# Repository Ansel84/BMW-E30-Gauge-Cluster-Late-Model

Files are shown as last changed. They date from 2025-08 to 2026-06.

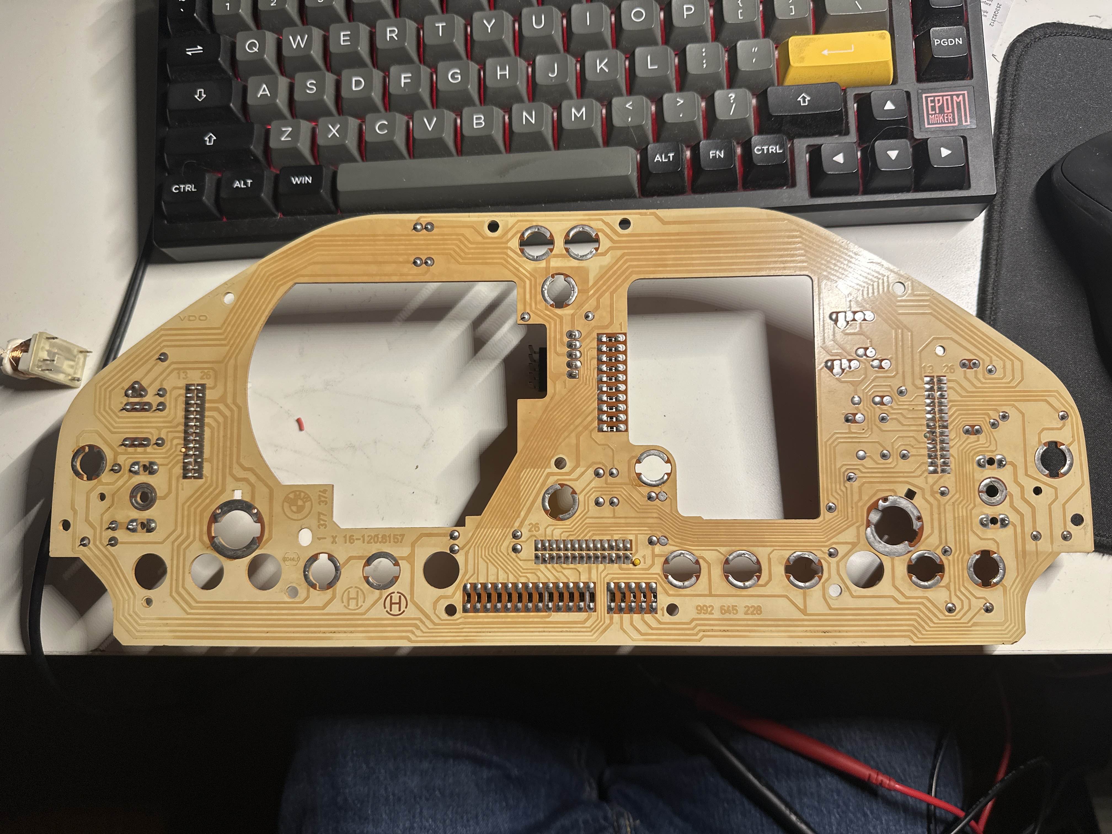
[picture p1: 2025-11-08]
BMW_E30_Late_Cluster_Nexus/Resources/VDO_Nexus_Layout.jpg

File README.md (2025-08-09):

# BMW E30 Gauge Cluster Late Model
The goal for this project is to reverse engineer every PCB in the gauge cluster for Late model year BMW E30's. This includes the main PCB referred to as the "Nexus" board, the SI (Service Interval) board, and the smaller boards that are part of the tachometer and speedometer gauge assemblies.

# Early Model Clusters:
If you have an early model cluster and need parts for that, check out the progress of the early model project here: https://github.com/Ansel84/BMW-E30-Gauge-Cluster-Early-Model

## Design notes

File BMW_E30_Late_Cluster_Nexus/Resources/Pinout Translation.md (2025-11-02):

# Stecker I SL 62 (blau / blue)
Pin	German	English
1	KL 50	Terminal 50 (starter signal)
2	KL 30	Terminal 30 (battery +)
3	Ladekontrolle KL 61	Charge indicator (terminal 61)
4	CHECK	Check control
5	Motronik	Motronic (engine control)
6	(KL 15)	Terminal 15 (ignition on)
7	KL TD	Engine speed signal (TD)
8	Rückwärtsgang	Reverse gear
9	5. Gang	5th gear
10	(KL 15)	Terminal 15 (ignition on)
11	KL 11	Terminal 11
12	KL 56a (Fernlicht)	Terminal 56a (high beam)
13	Blinker rechts	Right turn signal
14	Ladekontr. (KL 15)	Charge indicator (KL 15)
15	frei	Free / unused
16	Ladekontr. (KL 61)	Charge indicator (KL 61)
17	Bremse	Brake
18	Öldruck	Oil pressure
19	(KL 15)	Terminal 15 (ignition on)
20	(KL 31)	Terminal 31 (ground)
21	Bremsbelag 1	Brake pad wear sensor 1
22	Reset	Reset
23	KL 15	Terminal 15 (ignition on)
24	frei	Free / unused
25	Temp. warn	Temperature warning
26	Temp. Geber	Temperature sender
# Stecker II SL 61 (weiß / white)
Pin	German	English
1	Handbremse	Handbrake
2	frei	Free / unused
3	(KL 31)	Terminal 31 (ground)
4	Tank Geber	Fuel level sender
5	Tank warn	Fuel warning
6	KL 15	Terminal 15 (ignition on)
7	Blinker links	Left turn signal
8	(KL 31)	Terminal 31 (ground)
9	frei	Free / unused
10	A	Fuel warning lamp
11	frei	Free / unused
12	KL 31b	Terminal 31b
13	KL R	Terminal R (accessory on)
14	Nebelschlußleuchte	Rear fog lamp
15	frei	Free / unused
16	KL 31	Terminal 31 (ground)
17	frei	Free / unused
18	frei	Free / unused
19	frei	Free / unused
20	frei	Free / unused
21	(KL 31)	Terminal 31 (ground)
22	Nebelbeleucht. vorn	Front fog lamp
23	KL 58k	Terminal 58k (illumination)
24	KL 31g	Terminal 31g (ground group)
25	frei	Free / unused
26	Bremsbelag 2	Brake pad wear sensor 2
# Stecker III SL 60 (gelb / yellow)
Pin	German	English
1	KL 31	Terminal 31 (ground)
2	KL 15	Terminal 15 (ignition on)
3	(KL 31)	Terminal 31 (ground)
4	Tank warn	Fuel warning
5	Tank Geber	Fuel sender
6	(KL 31)	Terminal 31 (ground)
7	KL 58k	Terminal 58k (illumination)
8	KL 31g	Terminal 31g (ground group)
9	KL 50	Terminal 50 (starter signal)
10	KL 30	Terminal 30 (battery +)
11	KL TD	Engine speed signal (TD)
12	(KL 11)	Terminal 11
13	KL R	Terminal R (accessory on)
14	KL 15	Terminal 15 (ignition on)
15	KL 15	Terminal 15 (ignition on)
16	(KL 31)	Terminal 31 (ground)
17	(Tank warn)	Fuel warning
18	(Tank Geber)	Fuel sender
19	(KL 31)	Terminal 31 (ground)
20	KL 58k	Terminal 58k (illumination)
21	KL 31g	Terminal 31g (ground group)
22	KL 50	Terminal 50 (START)
23	KL 30	(Battery+ T30)
24	KL TD	Engine speed signal (TD)
25	KL 11	Fuel Rate Input
26	A	A
# Stecker IV SL 63 (grün / green)
Pin	German	English
1	KL R	Terminal R (accessory on)
2	A	Fuel warning lamp
3	KL 31b	Terminal 31b (ground)
4	KL 31	Terminal 31 (ground)
5	KL 61	Terminal 61 (charging system)
# KF 41–58 (rear connector block)
Pin	German	English
1	Temp. +Ub	Temp. + supply voltage
2	Temp. Masse	Temp. ground
3	Temp. Geber	Temperature sender
4	Reset	Reset
5	KL 15	Terminal 15 (ignition on)
6	NC
7	KL 31	Terminal 31 (ground)
8	KL 30	Terminal 30 (battery +)
9	KL TD	Engine speed signal (TD)
10	KL 11	Terminal 11
11	A	Wheel speed output
12	KVA Sp 2+	Current supply 2+
13	KVA Sp 2–	Current supply 2–
14	KVA Sp 1–	Current supply 1–
15	KVA Sp 1+	Current supply 1+
16	DZM Sp 1–	Tachometer signal 1–
17	DZM Sp 1+	Tachometer signal 1+
18	DZM Sp 2+	Tachometer signal 2+
19	DZM Sp 2–	Tachometer signal 2–
# Lamp Legend (bottom of page)
Letter	German	English
A	Tankwarnleuchte	Fuel warning lamp
B	Instrumentenbeleuchtung	Instrument illumination
C	Blinker links	Left turn indicator
D	Fernlicht	High beam
E	Blinker rechts	Right turn indicator
F	Temperaturwarnleuchte	Temperature warning lamp
G	Öldruck	Oil pressure warning lamp
H	Ladekontrolle	Battery charge indicator
I	Antiblockiersystem	Anti-lock braking system (ABS)
K	Bremskontrolle	Brake warning lamp
L	Bremsbelagverschleißanzeige	Brake pad wear indicator
M	Handbremse	Handbrake indicator
N	Anhängerblinker	Trailer turn indicator
O	Nebelschlußleuchte	Rear fog lamp
P	Nebelscheinwerfer	Front fog lamp
Q	Getriebeausfall	Transmission failure indicator
R	Start frei, Diesel	Diesel start permit
S	Vorglühen, Diesel	Diesel glow plug indicator
T	Check	Check control lamp

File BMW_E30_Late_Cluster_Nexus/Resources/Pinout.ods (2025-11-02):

Stecker 1
Pin | German | English
1 | KL50
2 | KL30
3 | Ladekontrolle KL61
4
5
6
7
8
9
10
11
12
13
14
15
16
17
18
19
20
21
22
23
24
25
26

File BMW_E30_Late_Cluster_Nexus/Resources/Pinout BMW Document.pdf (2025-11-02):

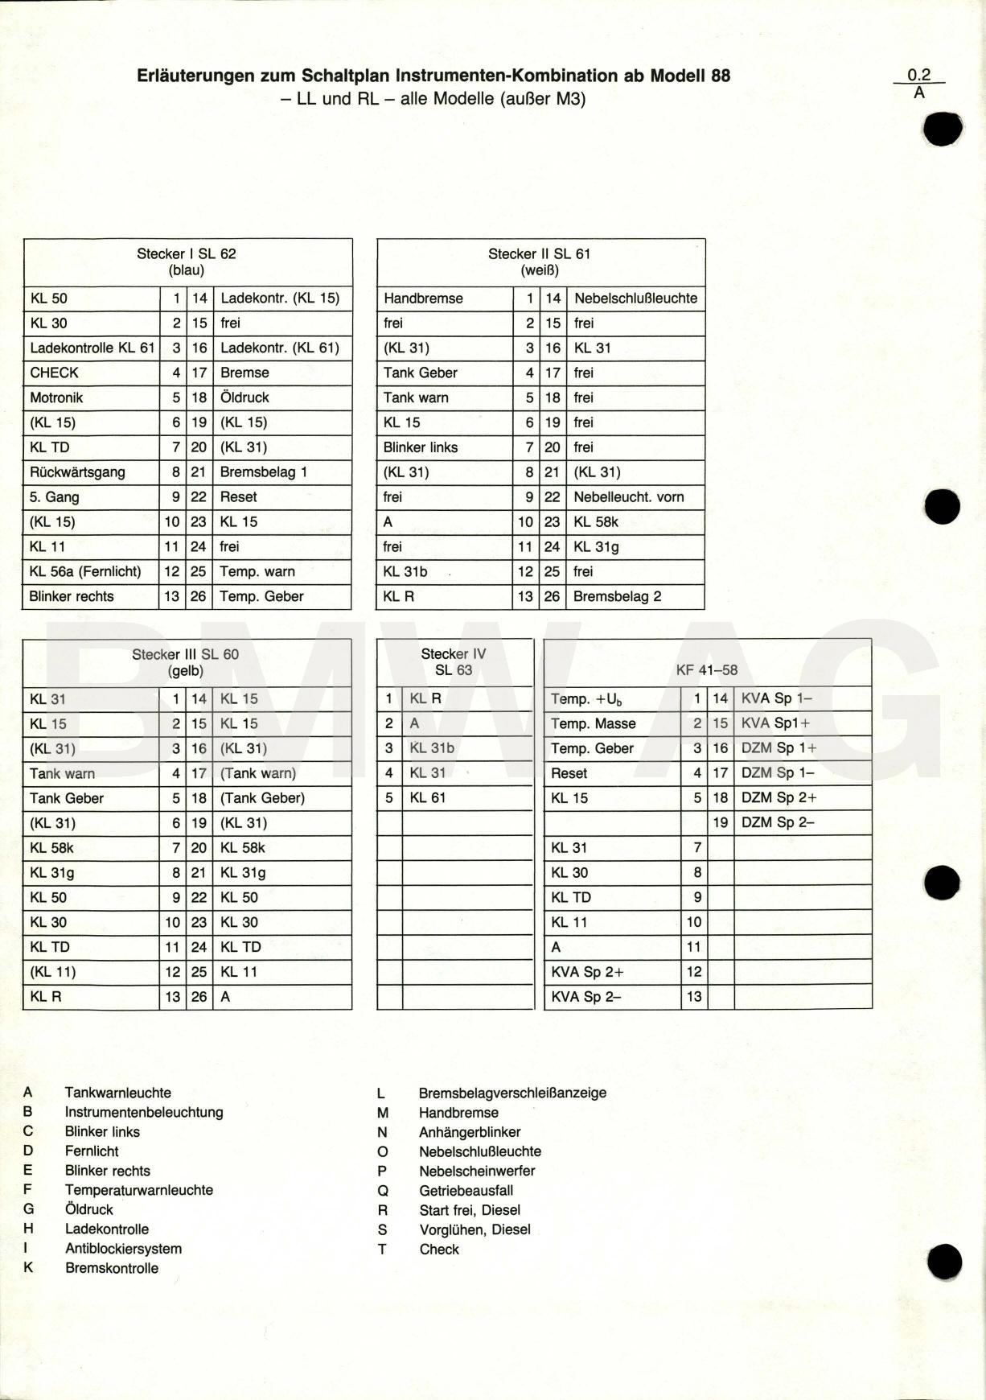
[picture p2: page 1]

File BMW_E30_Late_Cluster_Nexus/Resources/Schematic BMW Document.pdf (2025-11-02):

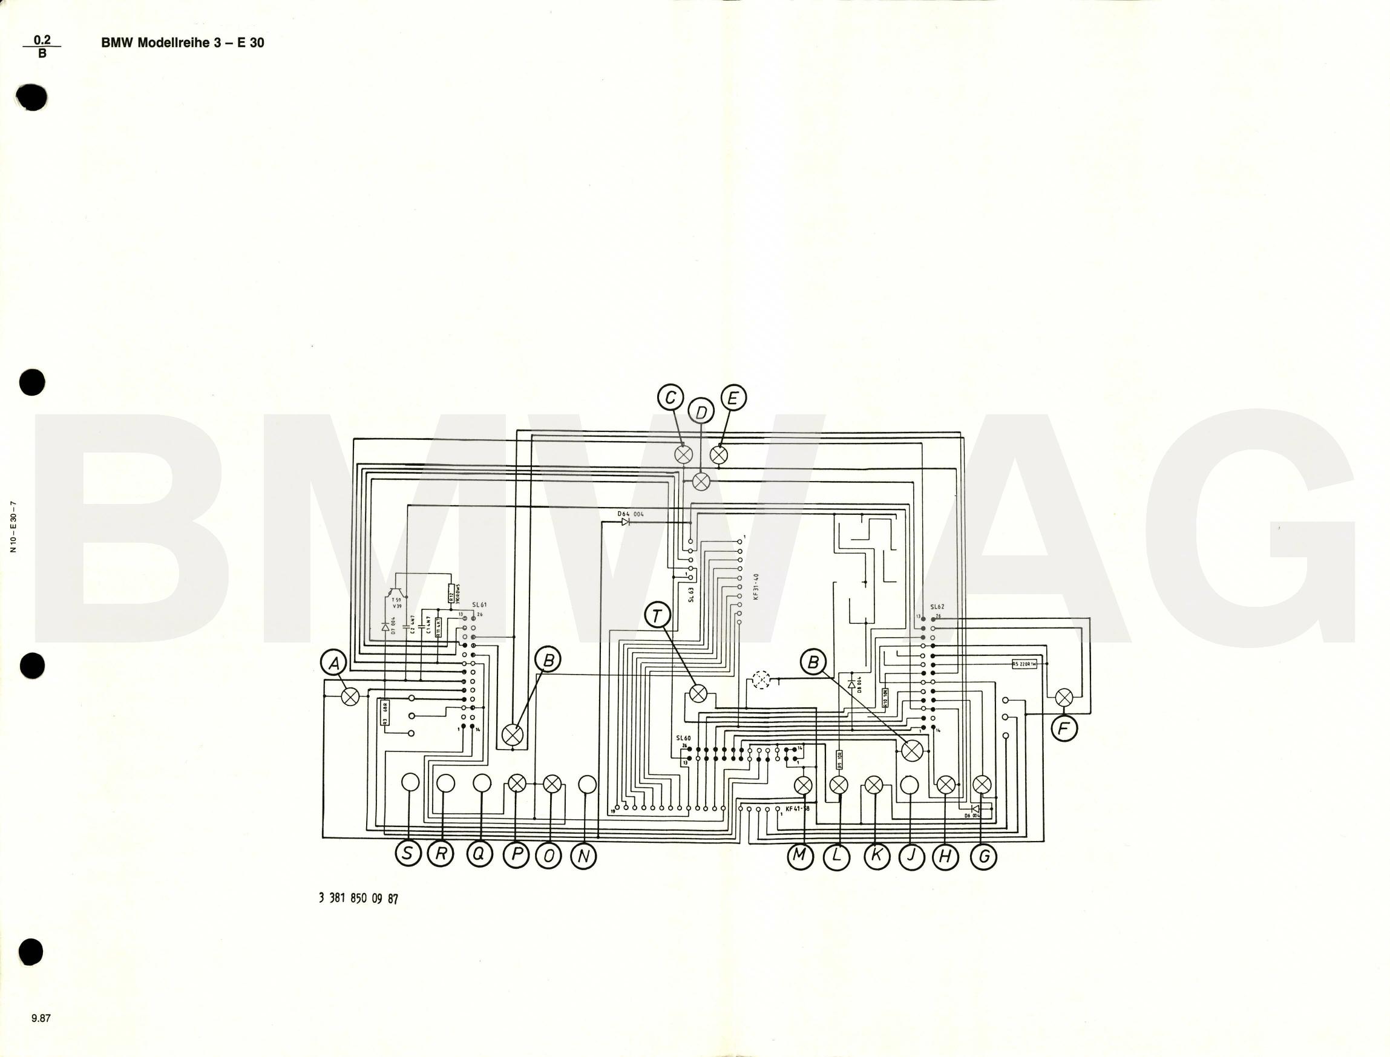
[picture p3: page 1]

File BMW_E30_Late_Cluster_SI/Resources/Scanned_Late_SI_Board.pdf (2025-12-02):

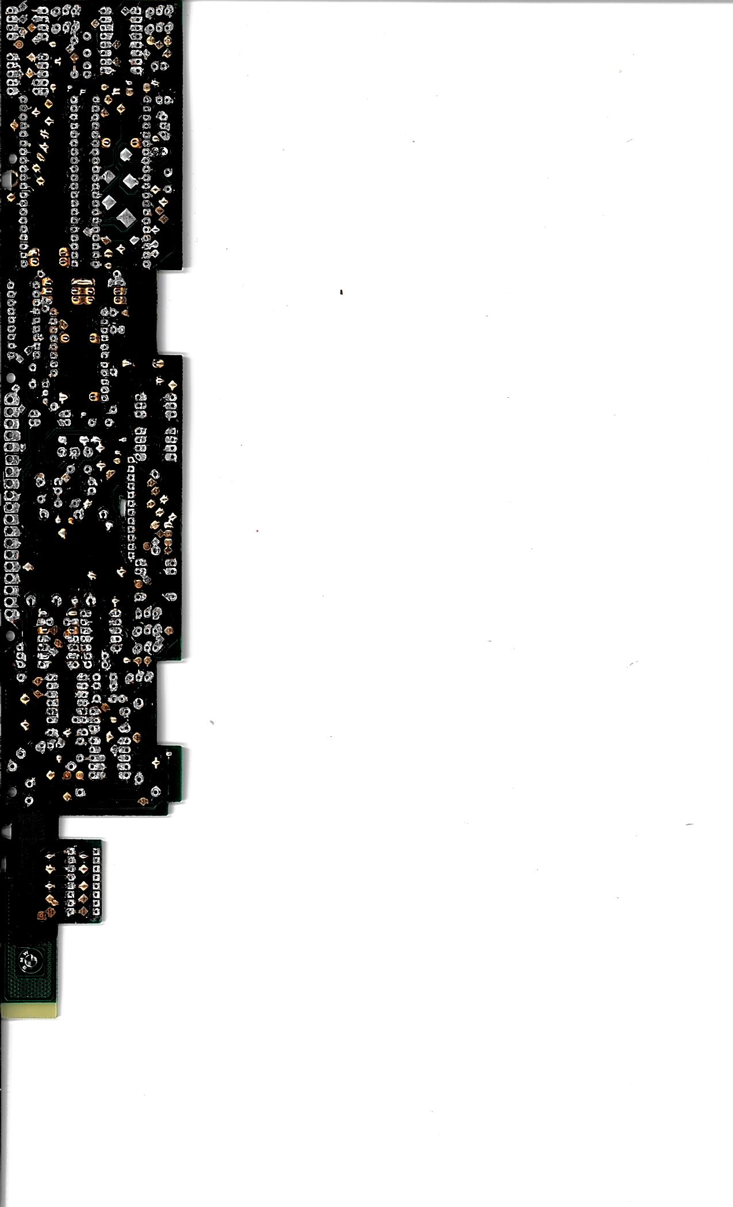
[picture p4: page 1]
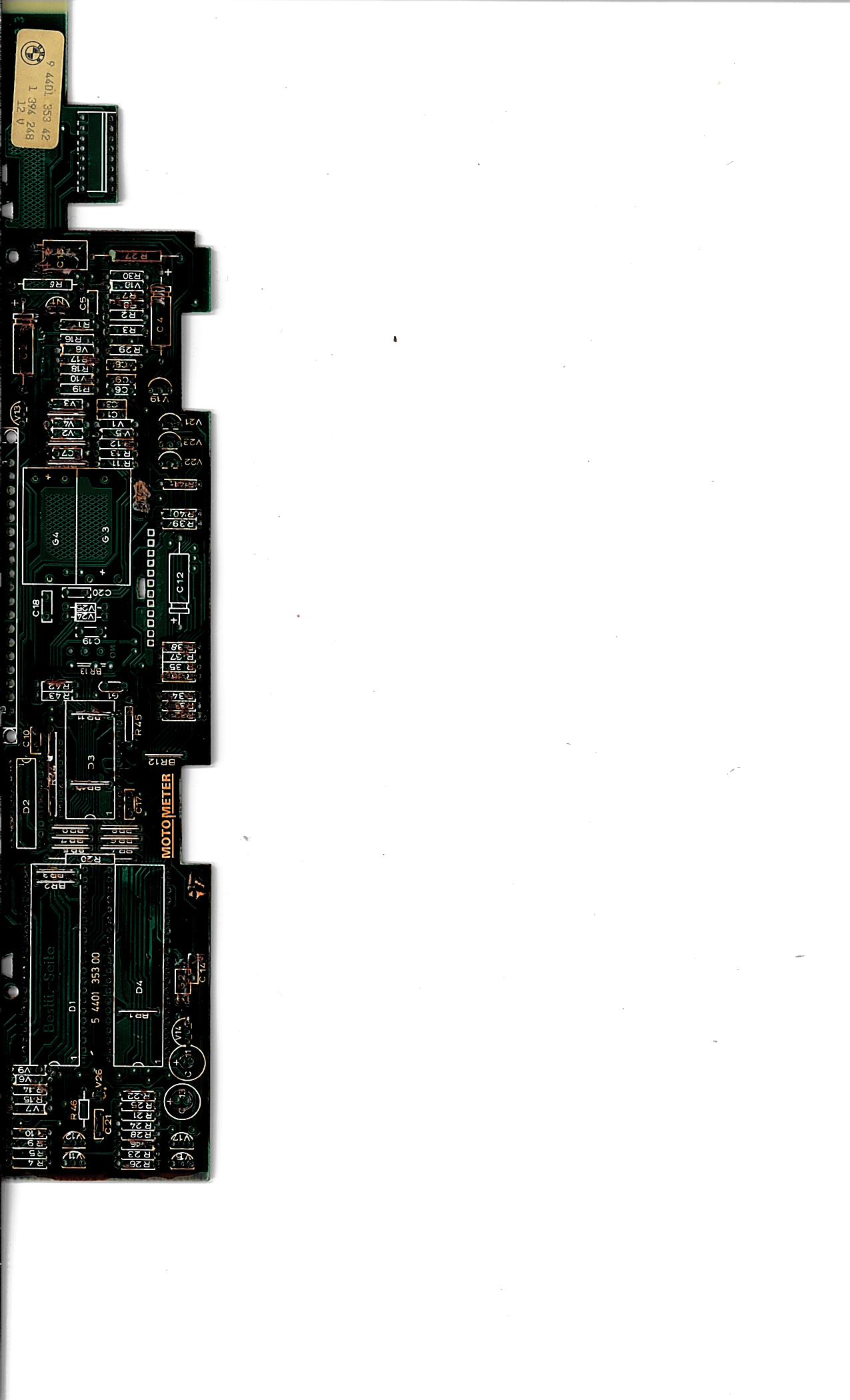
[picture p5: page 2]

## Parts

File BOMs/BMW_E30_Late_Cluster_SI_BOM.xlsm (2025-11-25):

Reference | Qty | Value
BT1,BT2 | 2 | 3V
C1,C3 | 2 | 0.1u
C2,C4,C12 | 3 | 100u
C5,C18 | 2 | 0.1u
C6 | 1 | 0.033u
C7 | 1 | 10n
C8 | 1 | 47n
C9,C10,C17 | 3 | 68n
C11 | 1 | 10u
C13 | 1 | 47u
C14 | 1 | 10n
C15 | 1 | 68u
C19,C20,C21 | 3 | 0.1n
D1,D4 | 2 | 1N4004
D2,D3,D6,D9 | 4 | BAV21
D5,D10 | 2 | BZX55C-5V1
D7 | 1 | BZX55C-4V7
D8 | 1 | ZW 4.7
D16 | 1 | BZX55C-9V1
D18 | 1 | 1N4148
D24,D25 | 2 | SD103A
D26 | 1 | LED
J1 | 1 | SI LED Board
J2 | 1 | Coding Plug
J5 | 1 | Nexus Connector
JP1 | 1 | Battery Jumper
Q11 | 1 | BC327-16
Q12,Q17,Q19,Q21,Q22,Q23 | 6 | BC337-25
Q13 | 1 | BC337-16
Q14 | 1 | BC547B
Q15 | 1 | BC557B
R1,R3 | 2 | 2R2
R2 | 1 | 15k
R4 | 1 | 6k8
R5,R9 | 2 | 4k6
R6 | 1 | 68R
R7,R17 | 2 | 27k
R8 | 1 | 3k92
R10 | 1 | 2k2
R11 | 1 | 2k21
R12,R21 | 2 | 10k
R13 | 1 | 27k4
R14,R15 | 2 | 47k
R16,R18 | 2 | 1k5
R19 | 1 | 470
R20 | 1 | 22k
R22 | 1 | 16k
R23 | 1 | 39k
R24 | 1 | 51k
R25,R46 | 2 | 100R
R26 | 1 | 1k
R27 | 1 | 47R
R28 | 1 | 200R
R29 | 1 | 100k
R30 | 1 | 75R
R32,R33,R34,R35,R36,R37,R38 | 7 | 160R
R39,R40,R41 | 3 | 4k7
R42,R43 | 2 | 82R
R44 | 1 | 2k
R45 | 1 | 1M
U1 | 1 | ITT SAF1190-196 MCU
U2 | 1 | ITT V3003-393
U3 | 1 | ITT V3004-520
U4 | 1 | ITT SAF1194-280 MCU
U5 | 1 | LP2950-5.0_TO92
Y1 | 1 | Crystal
Y2 | 1 | Crystal

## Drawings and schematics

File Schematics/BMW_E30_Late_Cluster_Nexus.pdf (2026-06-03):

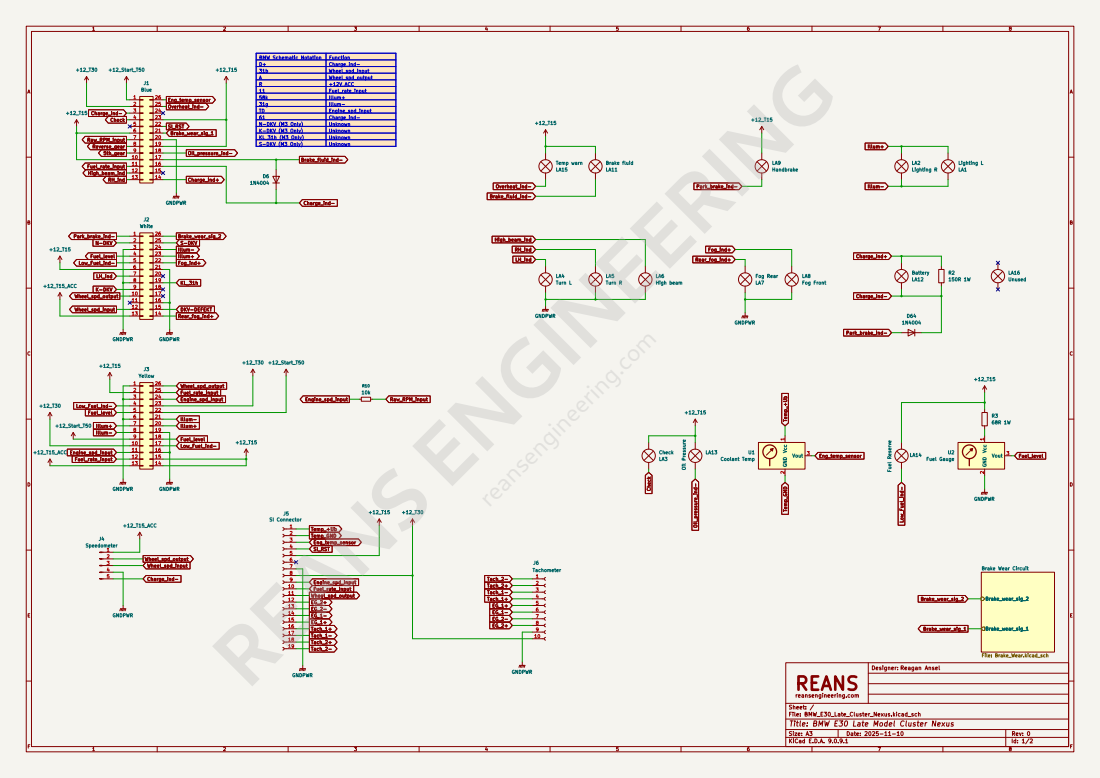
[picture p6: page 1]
REANS ENGINEERING; reansengineering.com

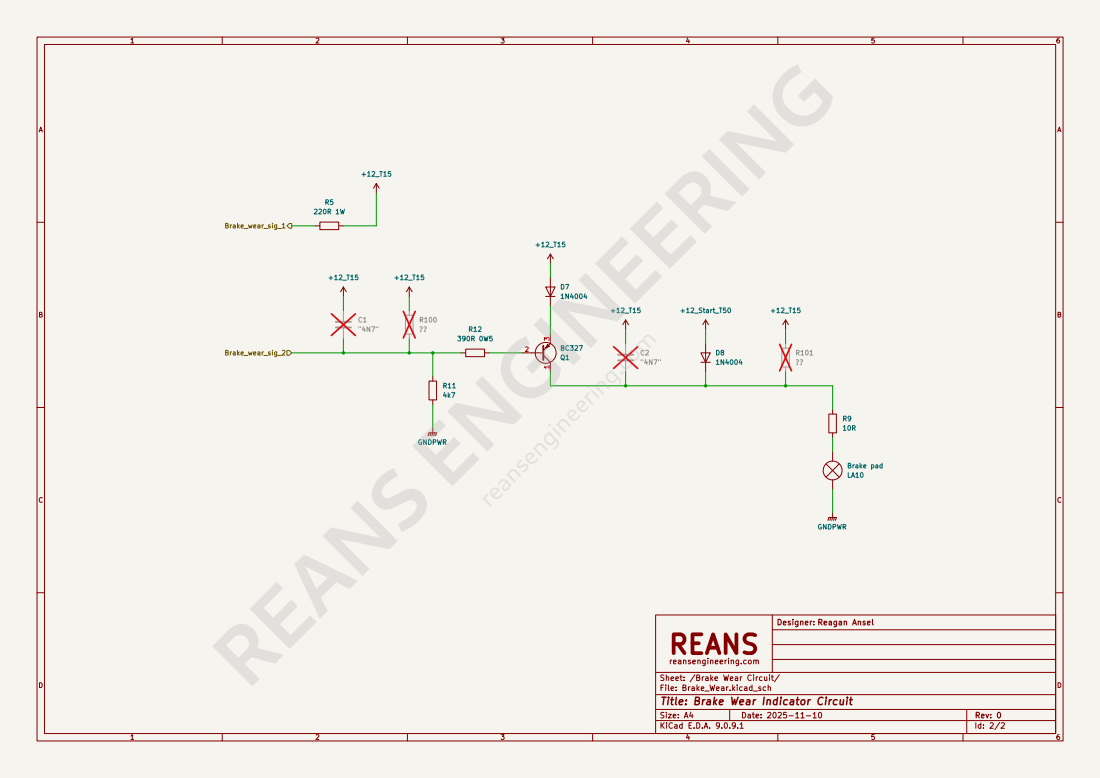
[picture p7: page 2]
REANS ENGINEERING; reansengineering.com

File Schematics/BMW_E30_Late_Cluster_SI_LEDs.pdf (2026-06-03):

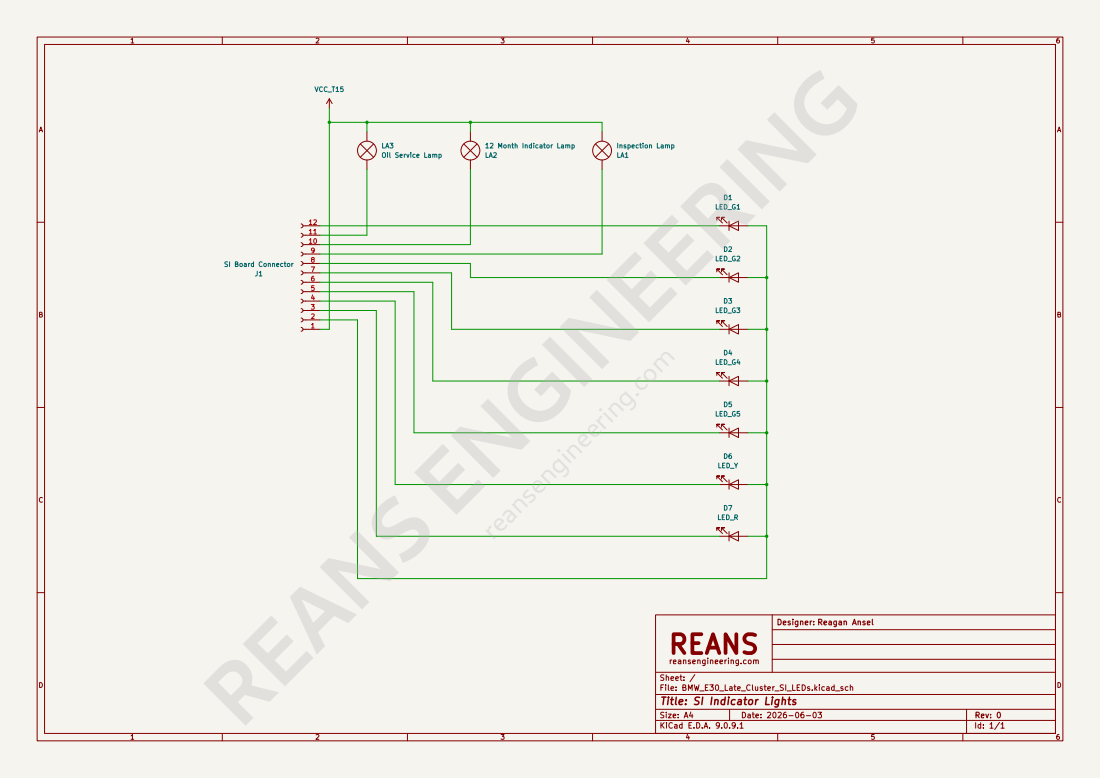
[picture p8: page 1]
REANS ENGINEERING; reansengineering.com

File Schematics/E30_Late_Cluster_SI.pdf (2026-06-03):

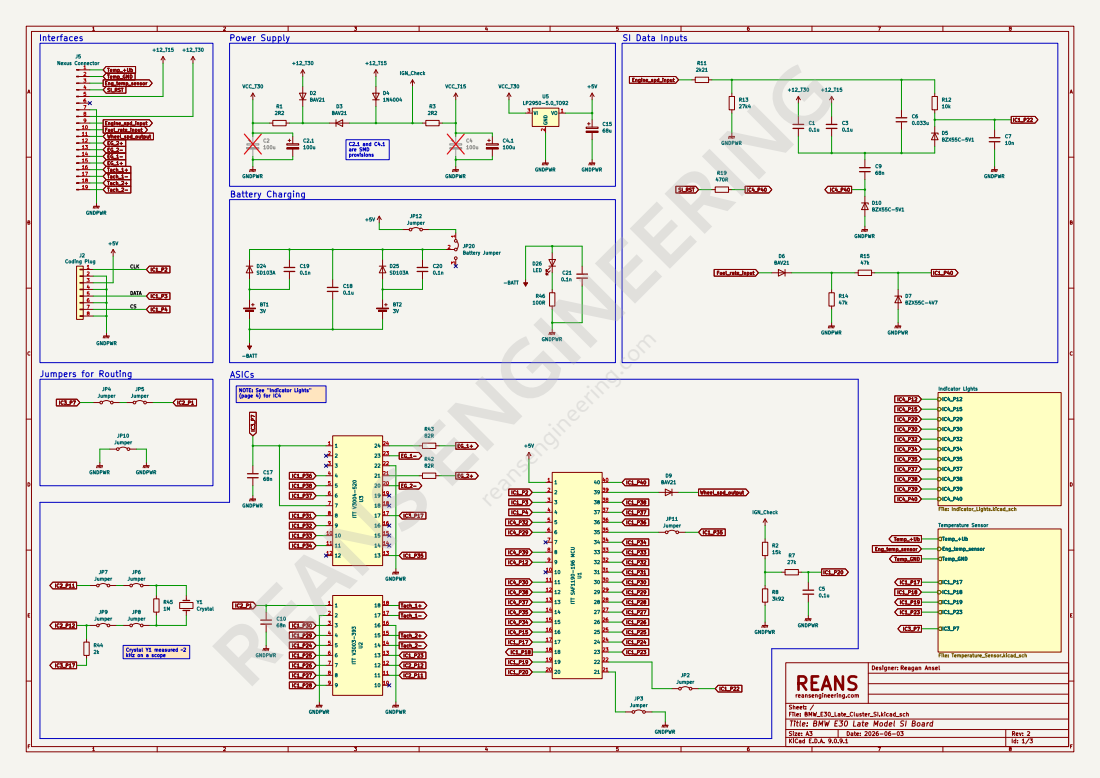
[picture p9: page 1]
REANS ENGINEERING; reansengineering.com

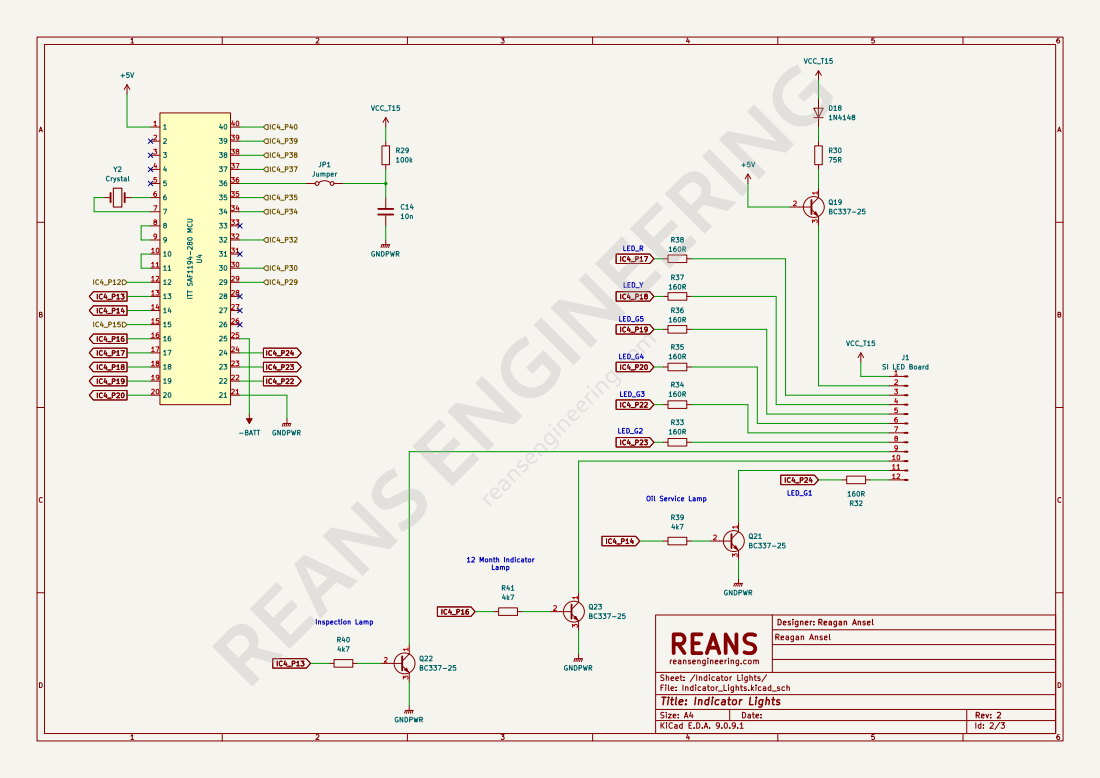
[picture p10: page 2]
REANS ENGINEERING; reansengineering.com

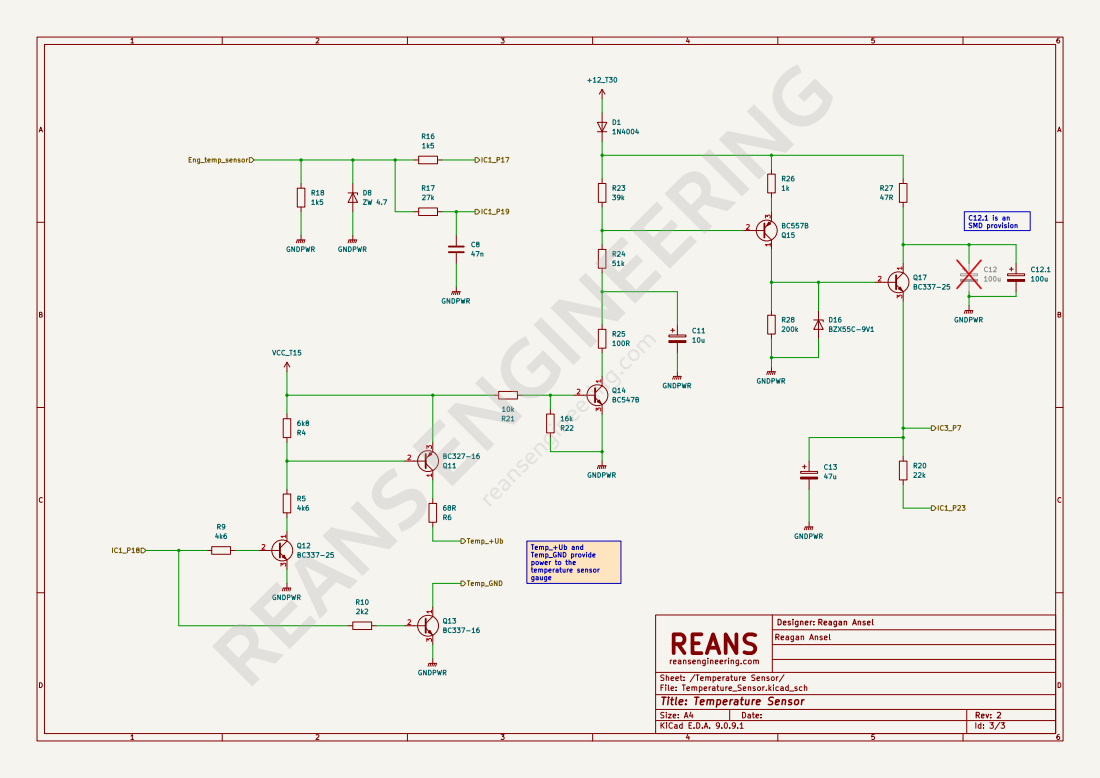
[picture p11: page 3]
REANS ENGINEERING; reansengineering.com

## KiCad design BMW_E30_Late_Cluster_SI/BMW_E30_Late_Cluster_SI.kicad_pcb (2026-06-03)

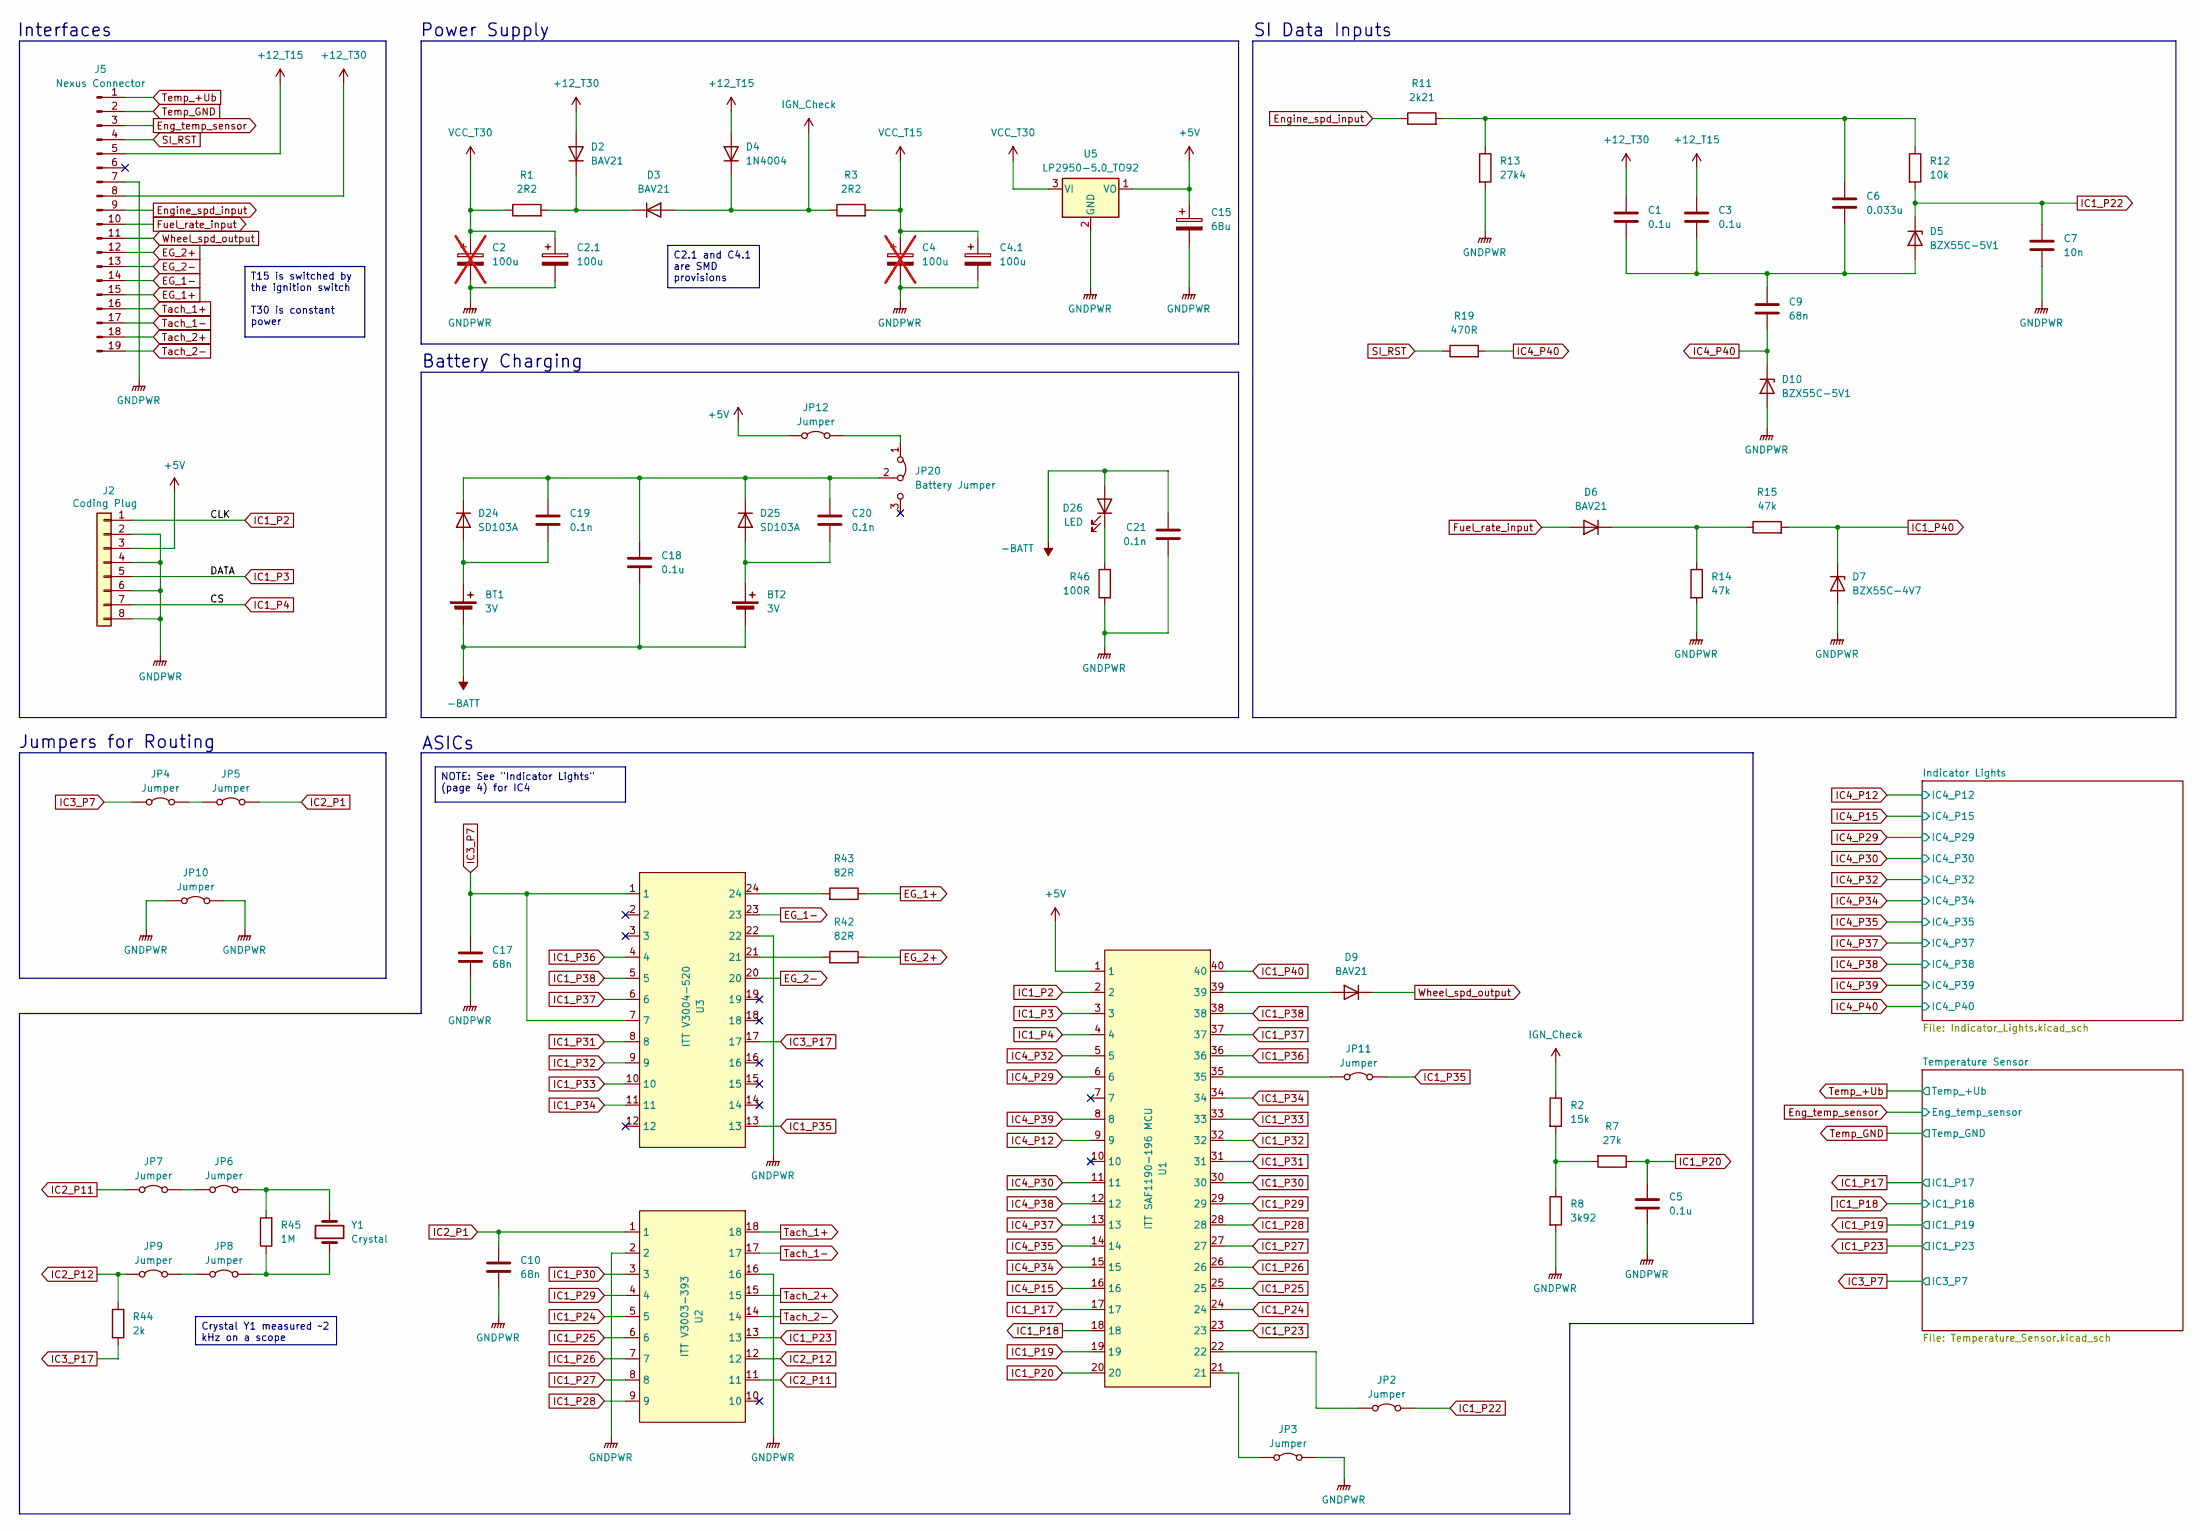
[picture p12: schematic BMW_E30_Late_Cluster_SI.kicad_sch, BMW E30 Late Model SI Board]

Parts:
BT1, BT2: 3V; Batt_CR14250SE
C1, C3: 0.1u; C_Disc_D6.0mm_W2.5mm_P5.00mm
C2, C4: 100u; CP_Axial_L18.0mm_D6.5mm_P25.00mm_Horizontal; not fitted
C2.1, C4.1: 100u; CP_Elec_6.3x5.8
C5, C18: 0.1u; C_Rect_L7.0mm_W2.0mm_P5.00mm
C6: 0.033u; C_Rect_L7.0mm_W2.0mm_P5.00mm
C7: 10n; C_Rect_L7.0mm_W2.0mm_P5.00mm
C9, C10, C17: 68n; C_Disc_D6.0mm_W2.5mm_P5.00mm
C15: 68u; CP_Radial_Tantal_D5.5mm_P5.00mm
C19, C20, C21: 0.1n; C_Disc_D6.0mm_W2.5mm_P5.00mm
D2, D3, D6, D9: BAV21; D_Axial_Narrow_L6.7mm_D2.4mm_P9.7mm
D4: 1N4004; D_Axial_Narrow_L6.7mm_D2.4mm_P9.7mm
D5, D10: BZX55C-5V1; D_Axial_Narrow_L6.7mm_D2.4mm_P9.7mm
D7: BZX55C-4V7; D_Axial_Narrow_L6.7mm_D2.4mm_P9.7mm
D24, D25: SD103A; D_Axial_Narrow_L6.7mm_D2.4mm_P9.7mm
D26: LED; LED_D3.0mm
J2: Coding Plug; PinSocket_1x08_P2.54mm_Horizontal
J5: Nexus Connector; E30_Early_SI_Conn_Late_P3.5
JP2, JP3, JP4, JP5, JP6, JP7, JP8, JP9, JP10, JP11, JP12: Jumper; Jumper_THT_P9.7mm
JP20: Battery Jumper; PinHeader_1x03_P2.54mm_Vertical
R1, R3: 2R2; R_Axial_Narrow_L6.8mm_D2.4mm_P9.7mm
R2: 15k; R_Axial_Narrow_L6.8mm_D2.4mm_P9.7mm
R7: 27k; R_Axial_Narrow_L6.8mm_D2.4mm_P9.7mm
R8: 3k92; R_Axial_Narrow_L6.8mm_D2.4mm_P9.7mm
R11: 2k21; R_Axial_Narrow_L6.8mm_D2.4mm_P9.7mm
R12: 10k; R_Axial_Narrow_L6.8mm_D2.4mm_P9.7mm
R13: 27k4; R_Axial_Narrow_L6.8mm_D2.4mm_P9.7mm
R14, R15: 47k; R_Axial_Narrow_L6.8mm_D2.4mm_P9.7mm
R19: 470R; R_Axial_Narrow_L6.8mm_D2.4mm_P9.7mm
R42, R43: 82R; R_Axial_Narrow_L6.8mm_D2.4mm_P9.7mm
R44: 2k; R_Axial_Narrow_L6.8mm_D2.4mm_P22.4mm
R45: 1M; R_Axial_Narrow_L6.8mm_D2.4mm_P9.7mm
R46: 100R; R_Axial_Narrow_L6.8mm_D2.4mm_P9.7mm
U1: ITT SAF1190-196 MCU; DIP-40_W15.24mm_LongPads
U2: ITT V3003-393; DIP-18_W7.62mm_LongPads
U3: ITT V3004-520; DIP-24_W15.24mm_LongPads
U5: LP2950-5.0_TO92; TO-92_Inline_Wide
Y1: Crystal; Crystal_HC18-U_Vertical

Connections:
+5V: C15.1, J2.3, JP12.1 (A), U1.1, U5.1 (VO); also elsewhere on the board
+12_T15: C3.1, D4.2 (A), J5.5
+12_T30: C1.1, D2.2 (A), J5.8; also elsewhere on the board
-BATT: BT1.2 (-), BT2.2 (-), C18.2, C21.1, D26.2 (A); also elsewhere on the board
EG_1+: J5.15, R43.1
EG_1-: J5.14, U3.23
EG_2+: J5.12, R42.1
EG_2-: J5.13, U3.20
Eng_temp_sensor: J5.3; also elsewhere on the board
Engine_spd_input: J5.9, R11.1
Fuel_rate_input: D6.2 (A), J5.10
GNDPWR: C2.2, C2.1.2, C4.2, C4.1.2, C5.2, C7.2, C10.2, C15.2, C17.2, C21.2, D7.2 (A), D10.2 (A), J2.2, J2.4, J2.6, J2.8, J5.7, JP3.1 (A), JP10.1 (A), JP10.2 (B), R8.2, R13.2, R14.2, R46.2, U2.2, U2.16, U3.22, U5.2 (GND); also elsewhere on the board
IC1_P2: J2.1, U1.2
IC1_P3: J2.5, U1.3
IC1_P4: J2.7, U1.4
IC1_P17: U1.17; also elsewhere on the board
IC1_P18: U1.18; also elsewhere on the board
IC1_P19: U1.19; also elsewhere on the board
IC1_P20: C5.1, R7.1, U1.20
IC1_P22: C7.1, D5.1 (K), JP2.1 (A), R12.2
IC1_P23: U1.23, U2.13; also elsewhere on the board
IC1_P24: U1.24, U2.5
IC1_P25: U1.25, U2.6
IC1_P26: U1.26, U2.7
IC1_P27: U1.27, U2.8
IC1_P28: U1.28, U2.9
IC1_P29: U1.29, U2.4
IC1_P30: U1.30, U2.3
IC1_P31: U1.31, U3.8
IC1_P32: U1.32, U3.9
IC1_P33: U1.33, U3.10
IC1_P34: U1.34, U3.11
IC1_P35: JP11.1 (A), U3.13
IC1_P36: U1.36, U3.4
IC1_P37: U1.37, U3.6
IC1_P38: U1.38, U3.5
IC1_P40: D7.1 (K), R15.2, U1.40
IC2_P1: C10.1, JP5.2 (B), U2.1
IC2_P11: JP7.2 (B), U2.11
IC2_P12: JP9.1 (A), R44.1, U2.12
IC3_P7: C17.1, JP4.1 (A), U3.1, U3.7; also elsewhere on the board
IC3_P17: R44.2, U3.17
IC4_P12: U1.9; also elsewhere on the board
IC4_P15: U1.16; also elsewhere on the board
IC4_P29: U1.6; also elsewhere on the board
IC4_P30: U1.11; also elsewhere on the board
IC4_P32: U1.5; also elsewhere on the board
IC4_P34: U1.15; also elsewhere on the board
IC4_P35: U1.14; also elsewhere on the board
IC4_P37: U1.13; also elsewhere on the board
IC4_P38: U1.12; also elsewhere on the board
IC4_P39: U1.8; also elsewhere on the board
IC4_P40: C9.2, D10.1 (K), R19.2; also elsewhere on the board
IGN_Check: D3.2 (A), D4.1 (K), R2.1, R3.1
unnamed: BT1.1 (+), C19.2, D24.2 (A)
unnamed: BT2.1 (+), C20.2, D25.2 (A)
unnamed: C6.1, R11.2, R12.1, R13.1
unnamed: D2.1 (K), D3.1 (K), R1.2
unnamed: C1.2, C3.2, C6.2, C9.1, D5.2 (A)
unnamed: D6.1 (K), R14.1, R15.1
unnamed: D9.2 (A), U1.39
unnamed: C18.1, C19.1, C20.1, D24.1 (K), D25.1 (K), JP20.2 (C)
unnamed: D26.1 (K), R46.1
unnamed: JP2.2 (B), U1.22
unnamed: JP3.2 (B), U1.21
unnamed: JP4.2 (B), JP5.1 (A)
unnamed: JP6.1 (A), JP7.1 (A)
unnamed: JP6.2 (B), R45.2, Y1.2
unnamed: JP8.1 (A), JP9.2 (B)
unnamed: JP8.2 (B), R45.1, Y1.1
unnamed: JP11.2 (B), U1.35
unnamed: JP12.2 (B), JP20.1 (A)
unnamed: R2.2, R7.2, R8.1
unnamed: R42.2, U3.21
unnamed: R43.2, U3.24
SI_RST: J5.4, R19.1
Tach_1+: J5.16, U2.18
Tach_1-: J5.17, U2.17
Tach_2+: J5.18, U2.15
Tach_2-: J5.19, U2.14
Temp_+Ub: J5.1; also elsewhere on the board
Temp_GND: J5.2; also elsewhere on the board
VCC_T15: C4.1, C4.1.1, R3.2; also elsewhere on the board
VCC_T30: C2.1, C2.1.1, R1.1, U5.3 (VI)
Wheel_spd_output: D9.1 (K), J5.11

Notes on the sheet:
Power Supply
Jumpers for Routing
Battery Charging
Interfaces
ASICs
SI Data Inputs
C2.1 and C4.1 are SMD provisions
T15 is switched by the ignition switch T30 is constant power
NOTE: See "Indicator Lights" (page 4) for IC4
Crystal Y1 measured ~2 kHz on a scope

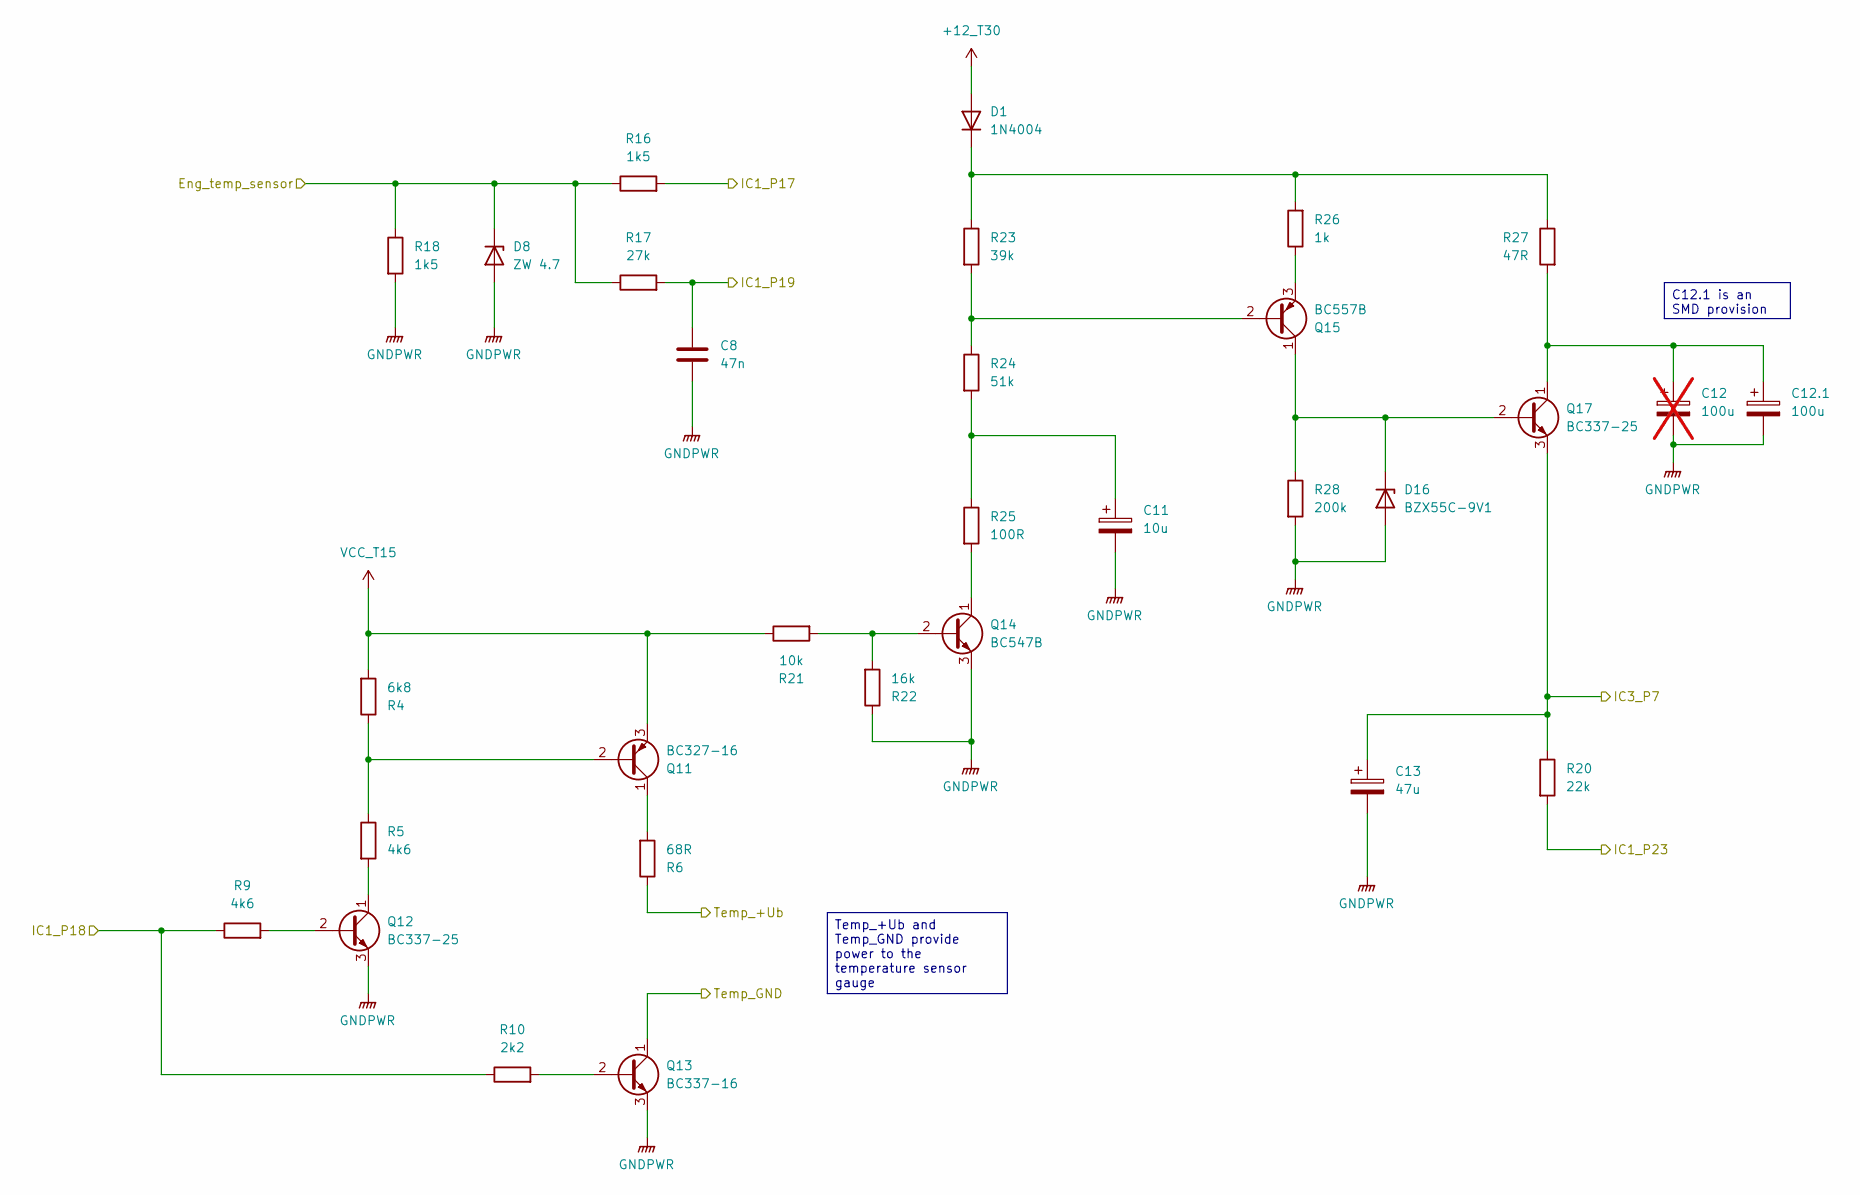
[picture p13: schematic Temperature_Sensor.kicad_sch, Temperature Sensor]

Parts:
C8: 47n; C_Disc_D6.0mm_W2.5mm_P5.00mm
C11: 10u; CP_Radial_Tantal_D8.0mm_P2.50mm
C12: 100u; CP_Axial_L18.0mm_D6.5mm_P25.00mm_Horizontal; not fitted
C12.1: 100u; CP_Elec_6.3x5.8
C13: 47u; CP_Radial_Tantal_D9.0mm_P2.50mm
D1: 1N4004; D_Axial_Narrow_L6.7mm_D2.4mm_P9.7mm
D8: ZW 4.7; D_Axial_Narrow_L6.7mm_D2.4mm_P9.7mm
D16: BZX55C-9V1; D_Axial_Narrow_L6.7mm_D2.4mm_P9.7mm
Q11: BC327-16; TO-92_Inline_Wide
Q12, Q17: BC337-25; TO-92_Inline_Wide
Q13: BC337-16; TO-92_Inline_Wide
Q14: BC547B; TO-92_Inline_Wide
Q15: BC557B; TO-92_Inline_Wide
R4: 6k8; R_Axial_Narrow_L6.8mm_D2.4mm_P9.7mm
R5, R9: 4k6; R_Axial_Narrow_L6.8mm_D2.4mm_P9.7mm
R6: 68R; R_Axial_DIN0414_L11.9mm_D4.5mm_P20.32mm_Horizontal
R10: 2k2; R_Axial_Narrow_L6.8mm_D2.4mm_P9.7mm
R16, R18: 1k5; R_Axial_Narrow_L6.8mm_D2.4mm_P9.7mm
R17: 27k; R_Axial_Narrow_L6.8mm_D2.4mm_P9.7mm
R20: 22k; R_Axial_DIN0207_L6.3mm_D2.5mm_P22.2mm_Horizontal
R21: 10k; R_Axial_Narrow_L6.8mm_D2.4mm_P9.7mm
R22: 16k; R_Axial_Narrow_L6.8mm_D2.4mm_P9.7mm
R23: 39k; R_Axial_Narrow_L6.8mm_D2.4mm_P9.7mm
R24: 51k; R_Axial_Narrow_L6.8mm_D2.4mm_P9.7mm
R25: 100R; R_Axial_Narrow_L6.8mm_D2.4mm_P9.7mm
R26: 1k; R_Axial_Narrow_L6.8mm_D2.4mm_P9.7mm
R27: 47R; R_Axial_DIN0516_L15.5mm_D5.0mm_P20.32mm_Horizontal
R28: 200k; R_Axial_Narrow_L6.8mm_D2.4mm_P9.7mm

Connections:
+12_T30: D1.2 (A); also elsewhere on the board
Eng_temp_sensor: D8.1 (K), R16.1, R17.1, R18.1; also elsewhere on the board
GNDPWR: C8.2, C11.2, C12.2, C12.1.2, C13.2, D8.2 (A), D16.2 (A), Q12.3 (E), Q13.3 (E), Q14.3 (E), R18.2, R22.1, R28.2; also elsewhere on the board
IC1_P17: R16.2; also elsewhere on the board
IC1_P18: R9.1, R10.1; also elsewhere on the board
IC1_P19: C8.1, R17.2; also elsewhere on the board
IC1_P23: R20.2; also elsewhere on the board
IC3_P7: C13.1, Q17.3 (E), R20.1; also elsewhere on the board
unnamed: C11.1, R24.2, R25.1
unnamed: D1.1 (K), R23.1, R26.2, R27.1
unnamed: D16.1 (K), Q15.1 (C), Q17.2 (B), R28.1
unnamed: Q11.2 (B), R4.1, R5.1
unnamed: Q11.1 (C), R6.2
unnamed: Q12.2 (B), R9.2
unnamed: Q12.1 (C), R5.2
unnamed: Q13.2 (B), R10.2
unnamed: Q14.2 (B), R21.2, R22.2
unnamed: Q14.1 (C), R25.2
unnamed: Q15.2 (B), R23.2, R24.1
unnamed: Q15.3 (E), R26.1
unnamed: C12.1, C12.1.1, Q17.1 (C), R27.2
Temp_+Ub: R6.1; also elsewhere on the board
Temp_GND: Q13.1 (C); also elsewhere on the board
VCC_T15: Q11.3 (E), R4.2, R21.1; also elsewhere on the board

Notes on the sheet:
Temp_+Ub and Temp_GND provide power to the temperature sensor gauge
C12.1 is an SMD provision

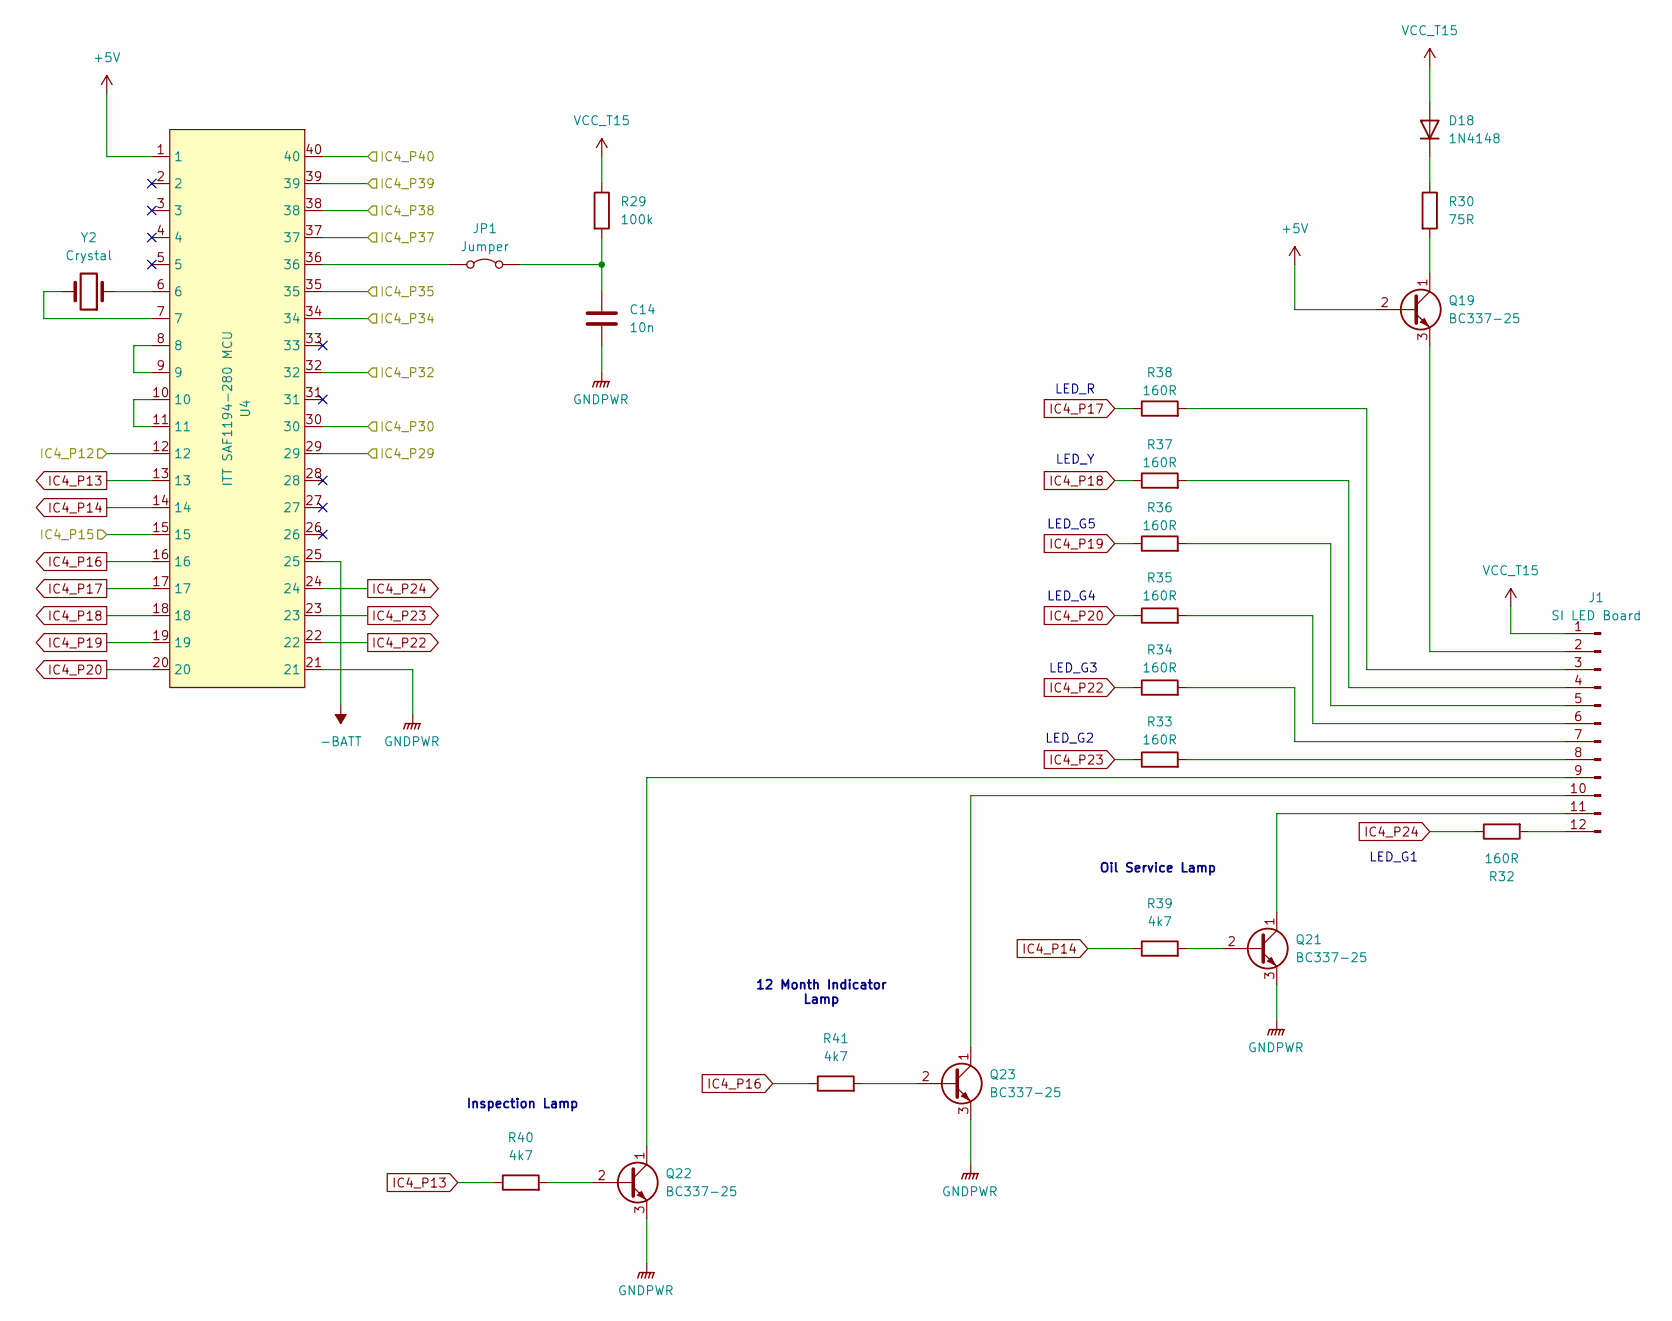
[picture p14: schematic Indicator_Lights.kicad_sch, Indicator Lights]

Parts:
C14: 10n; C_Disc_D6.0mm_W2.5mm_P5.00mm
D18: 1N4148; D_Axial_Narrow_L6.7mm_D2.4mm_P9.7mm
J1: SI LED Board; SILight_1x12_P2.54mm_Vertical_PinHeader
JP1: Jumper; Jumper_THT_P9.7mm
Q19, Q21, Q22, Q23: BC337-25; TO-92_Inline_Wide
R29: 100k; R_Axial_Narrow_L6.8mm_D2.4mm_P9.7mm
R30: 75R; R_Axial_Narrow_L6.8mm_D2.4mm_P9.7mm
R32, R33, R34, R35, R36, R37, R38: 160R; R_Axial_Narrow_L6.8mm_D2.4mm_P9.7mm
R39, R40, R41: 4k7; R_Axial_Narrow_L6.8mm_D2.4mm_P9.7mm
U4: ITT SAF1194-280 MCU; DIP-40_W15.24mm_LongPads
Y2: Crystal; Crystal_C38-LF_D3.0mm_L8.0mm_Horizontal

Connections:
+5V: Q19.2 (B), U4.1; also elsewhere on the board
-BATT: U4.25; also elsewhere on the board
GNDPWR: C14.2, Q21.3 (E), Q22.3 (E), Q23.3 (E), U4.21; also elsewhere on the board
IC4_P12: U4.12; also elsewhere on the board
IC4_P13: R40.1, U4.13
IC4_P14: R39.1, U4.14
IC4_P15: U4.15; also elsewhere on the board
IC4_P16: R41.1, U4.16
IC4_P17: R38.1, U4.17
IC4_P18: R37.1, U4.18
IC4_P19: R36.1, U4.19
IC4_P20: R35.1, U4.20
IC4_P22: R34.1, U4.22
IC4_P23: R33.1, U4.23
IC4_P24: R32.1, U4.24
IC4_P29: U4.29; also elsewhere on the board
IC4_P30: U4.30; also elsewhere on the board
IC4_P32: U4.32; also elsewhere on the board
IC4_P34: U4.34; also elsewhere on the board
IC4_P35: U4.35; also elsewhere on the board
IC4_P37: U4.37; also elsewhere on the board
IC4_P38: U4.38; also elsewhere on the board
IC4_P39: U4.39; also elsewhere on the board
IC4_P40: U4.40; also elsewhere on the board
unnamed: D18.1 (K), R30.1
unnamed: J1.2, Q19.3 (E)
unnamed: J1.3, R38.2
unnamed: J1.4, R37.2
unnamed: J1.5, R36.2
unnamed: J1.6, R35.2
unnamed: J1.7, R34.2
unnamed: J1.8, R33.2
unnamed: J1.9, Q22.1 (C)
unnamed: J1.10, Q23.1 (C)
unnamed: J1.11, Q21.1 (C)
unnamed: J1.12, R32.2
unnamed: JP1.1 (A), U4.36
unnamed: C14.1, JP1.2 (B), R29.2
unnamed: Q19.1 (C), R30.2
unnamed: Q21.2 (B), R39.2
unnamed: Q22.2 (B), R40.2
unnamed: Q23.2 (B), R41.2
unnamed: U4.6, Y2.1
unnamed: U4.7, Y2.2
unnamed: U4.8, U4.9
unnamed: U4.10, U4.11
VCC_T15: D18.2 (A), J1.1, R29.1; also elsewhere on the board

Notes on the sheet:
Oil Service Lamp
LED_G1
LED_G3
LED_G5
LED_R
Inspection Lamp
LED_G2
LED_Y
12 Month Indicator Lamp
LED_G4

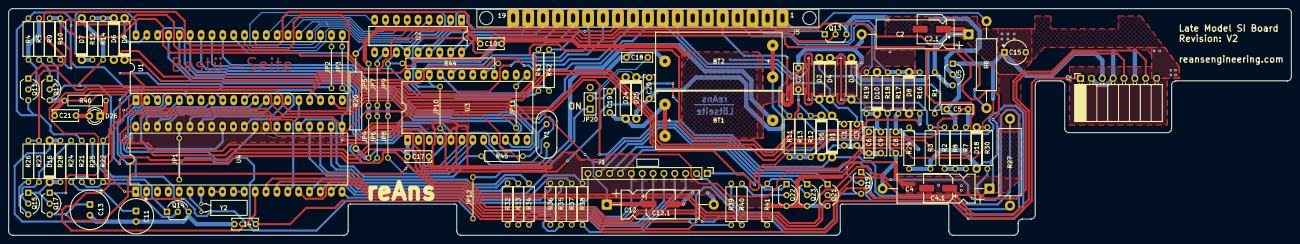
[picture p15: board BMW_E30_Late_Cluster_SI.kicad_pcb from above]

Board: 2 copper layers, 300.0 x 53.0 mm, 118 parts (0 on the bottom side), 130 nets.

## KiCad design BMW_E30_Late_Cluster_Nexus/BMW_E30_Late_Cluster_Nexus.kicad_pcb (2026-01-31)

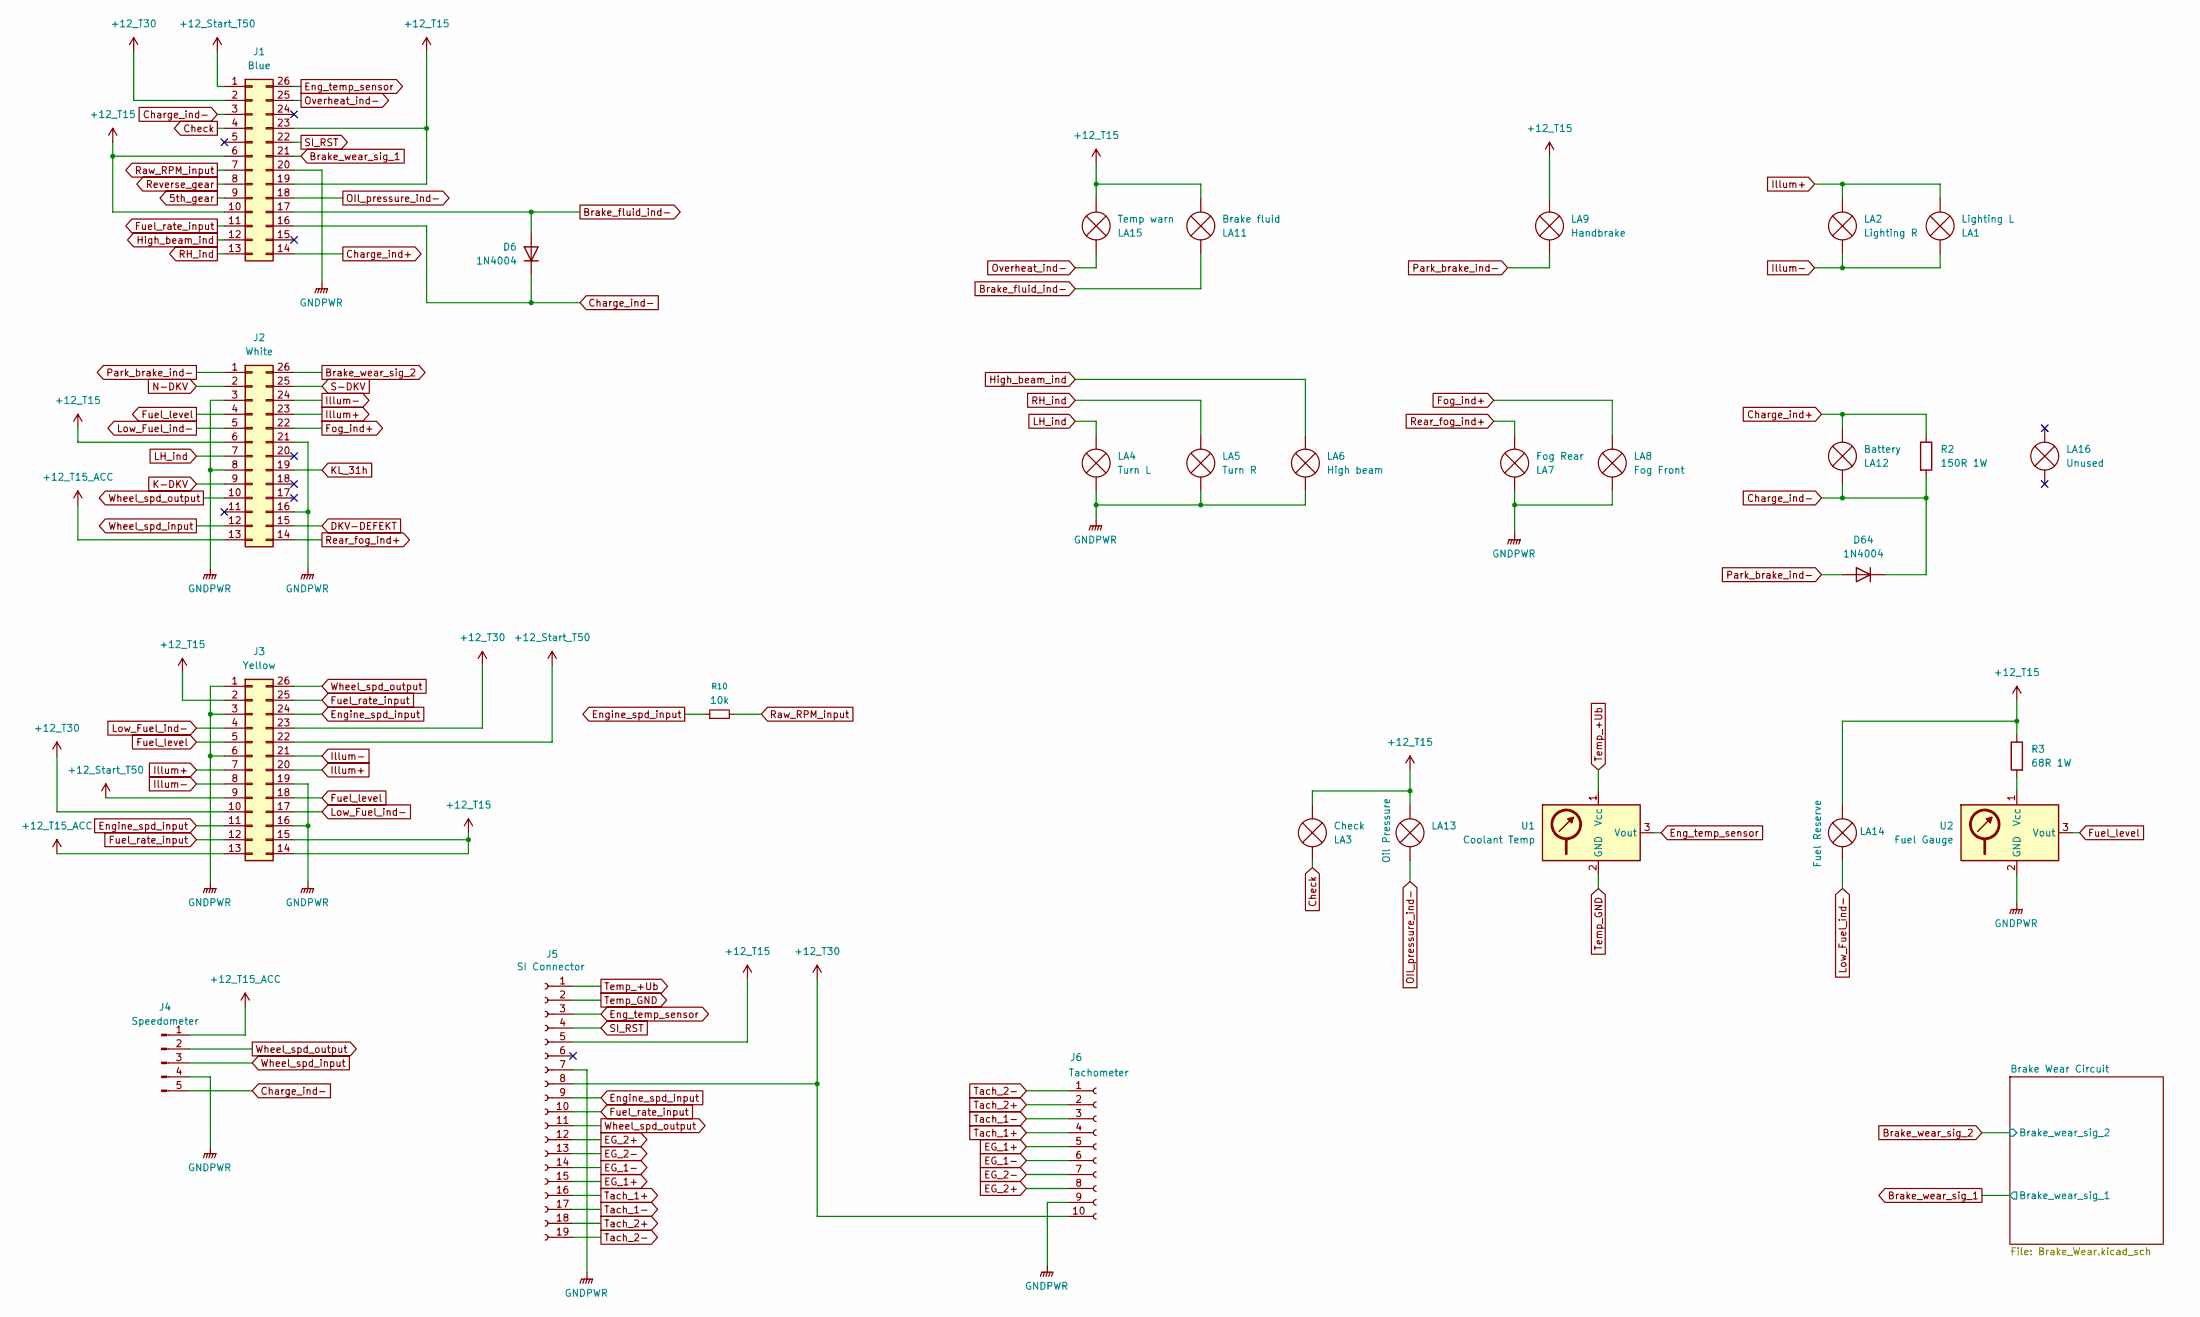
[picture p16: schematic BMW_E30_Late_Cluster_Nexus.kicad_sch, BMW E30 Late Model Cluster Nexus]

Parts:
D6: 1N4004; D_DO-41_SOD81_P12.70mm_Horizontal
D64: 1N4004; D_DO-41_SOD81_P10.16mm_Horizontal
J1: Blue; TE_827881-3
J2: White; TE_827881-2
J3: Yellow; TE_827881-1
J4: Speedometer; ConnectorIV_Late
J5: SI Connector; ConnectorV_Late_V2
J6: Tachometer; Tach_EG_Socket_Late
LA1: Lighting L; 2821MF
LA2: Lighting R; 2821MF
LA3: Check; 2721MF
LA4: Turn L; 2721MF
LA5: Turn R; 2721MF
LA6: High beam; 2721MF
LA7: Fog Rear; 2721MF
LA8: Fog Front; 2721MF
LA9: Handbrake; 2721MF
LA11: Brake fluid; 2721MF
LA12: Battery; 2721MF
LA13: Oil Pressure; 2721MF
LA14: Fuel Reserve; 2721MF
LA15: Temp warn; 2721MF
LA16: Unused; 2721MF
R2: 150R 1W; R_Axial_DIN0414_L11.9mm_D4.5mm_P20.32mm_Horizontal; Digikey Part # A131434CT-ND
R3: 68R 1W; R_Axial_DIN0414_L11.9mm_D4.5mm_P20.32mm_Horizontal
R10: 10k; R_Axial_DIN0207_L6.3mm_D2.5mm_P10.16mm_Horizontal
U1: Coolant Temp; Gauge_Temp
U2: Fuel Gauge; Gauge_Fuel

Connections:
5th_gear: J1.9
+12_Start_T50: J1.1, J3.9, J3.22; also elsewhere on the board
+12_T15: J1.6, J1.10, J1.19, J1.23, J2.6, J3.2, J3.14, J3.15, J5.5, LA3.1 (-), LA9.1 (-), LA11.2 (+), LA13.2 (+), LA14.1 (-), LA15.1 (-), R3.1; also elsewhere on the board
+12_T15_ACC: J2.13, J3.13, J4.1
+12_T30: J1.2, J3.10, J3.23, J5.8, J6.10
Brake_fluid_ind-: D6.2 (A), J1.17, LA11.1 (-)
Brake_wear_sig_1: J1.21; also elsewhere on the board
Brake_wear_sig_2: J2.26; also elsewhere on the board
Charge_ind+: J1.14, LA12.1 (-), R2.1
Charge_ind-: D6.1 (K), D64.1 (K), J1.3, J1.16, J4.5, LA12.2 (+), R2.2
Check: J1.4, LA3.2 (+)
DKV-DEFEKT: J2.15
EG_1+: J5.15, J6.5
EG_1-: J5.14, J6.6
EG_2+: J5.12, J6.8
EG_2-: J5.13, J6.7
Eng_temp_sensor: J1.26, J5.3, U1.3 (Vout)
Engine_spd_input: J3.11, J3.24, J5.9, R10.1
Fog_ind+: J2.22, LA8.1 (-)
Fuel_level: J2.4, J3.5, J3.18, U2.3 (Vout)
Fuel_rate_input: J1.11, J3.12, J3.25, J5.10
GNDPWR: J1.20, J2.3, J2.8, J2.16, J2.21, J3.1, J3.3, J3.6, J3.16, J3.19, J4.4, J5.7, J6.9, LA4.2 (+), LA5.2 (+), LA6.1 (-), LA7.1 (-), LA8.2 (+), U2.2 (GND); also elsewhere on the board
High_beam_ind: J1.12, LA6.2 (+)
Illum+: J2.23, J3.7, J3.20, LA1.2 (+), LA2.1 (-)
Illum-: J2.24, J3.8, J3.21, LA1.1 (-), LA2.2 (+)
K-DKV: J2.9
KL_31h: J2.19
LH_ind: J2.7, LA4.1 (-)
Low_Fuel_ind-: J2.5, J3.4, J3.17, LA14.2 (+)
N-DKV: J2.2
unnamed: R3.2, U2.1 (Vcc)
OIl_pressure_ind-: J1.18, LA13.1 (-)
Overheat_ind-: J1.25, LA15.2 (+)
Park_brake_ind-: D64.2 (A), J2.1, LA9.2 (+)
RH_ind: J1.13, LA5.1 (-)
Raw_RPM_input: J1.7, R10.2
Rear_fog_ind+: J2.14, LA7.2 (+)
Reverse_gear: J1.8
S-DKV: J2.25
SI_RST: J1.22, J5.4
Tach_1+: J5.16, J6.4
Tach_1-: J5.17, J6.3
Tach_2+: J5.18, J6.2
Tach_2-: J5.19, J6.1
Temp_+Ub: J5.1, U1.1 (Vcc)
Temp_GND: J5.2, U1.2 (GND)
Wheel_spd_input: J2.12, J4.3
Wheel_spd_output: J2.10, J3.26, J4.2, J5.11

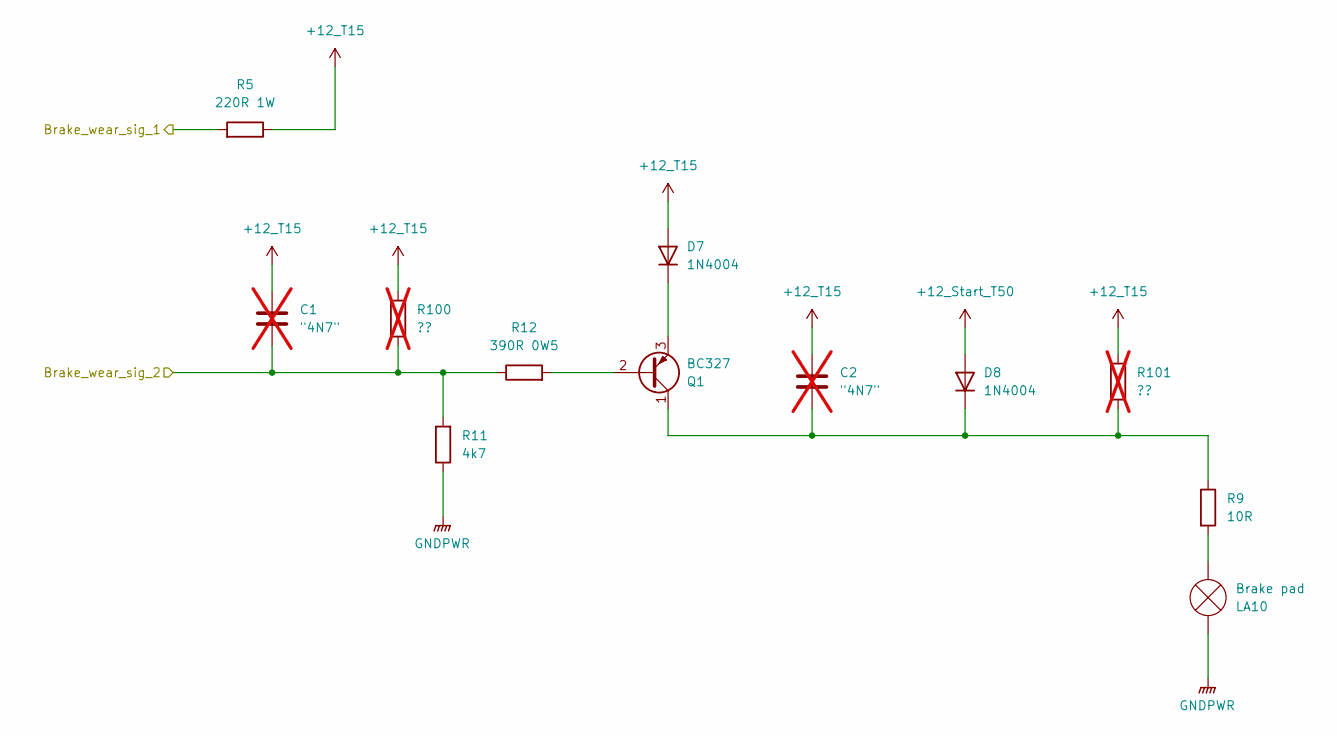
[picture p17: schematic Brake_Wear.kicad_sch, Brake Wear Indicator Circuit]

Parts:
C1, C2: "4N7"; not fitted
D7, D8: 1N4004; D_DO-41_SOD81_P12.70mm_Horizontal
LA10: Brake pad; 2721MF
Q1: BC327; TO-92_Inline_Wide
R5: 220R 1W; R_Axial_DIN0414_L11.9mm_D4.5mm_P20.32mm_Horizontal
R9: 10R; R_Axial_DIN0207_L6.3mm_D2.5mm_P15.24mm_Horizontal
R11: 4k7; R_Axial_DIN0207_L6.3mm_D2.5mm_P15.24mm_Horizontal
R12: 390R 0W5; R_Axial_DIN0309_L9.0mm_D3.2mm_P15.24mm_Horizontal
R100, R101: ??; R_Axial_DIN0207_L6.3mm_D2.5mm_P15.24mm_Horizontal; not fitted

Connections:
+12_Start_T50: D8.2 (A); also elsewhere on the board
+12_T15: C1.1, C2.1, D7.2 (A), R5.1, R100.2, R101.2; also elsewhere on the board
Brake_wear_sig_1: R5.2; also elsewhere on the board
Brake_wear_sig_2: C1.2, R11.2, R12.1, R100.1; also elsewhere on the board
GNDPWR: LA10.1 (-), R11.1; also elsewhere on the board
unnamed: D7.1 (K), Q1.3 (E)
unnamed: C2.2, D8.1 (K), Q1.1 (C), R9.1, R101.1
unnamed: LA10.2 (+), R9.2
unnamed: Q1.2 (B), R12.2

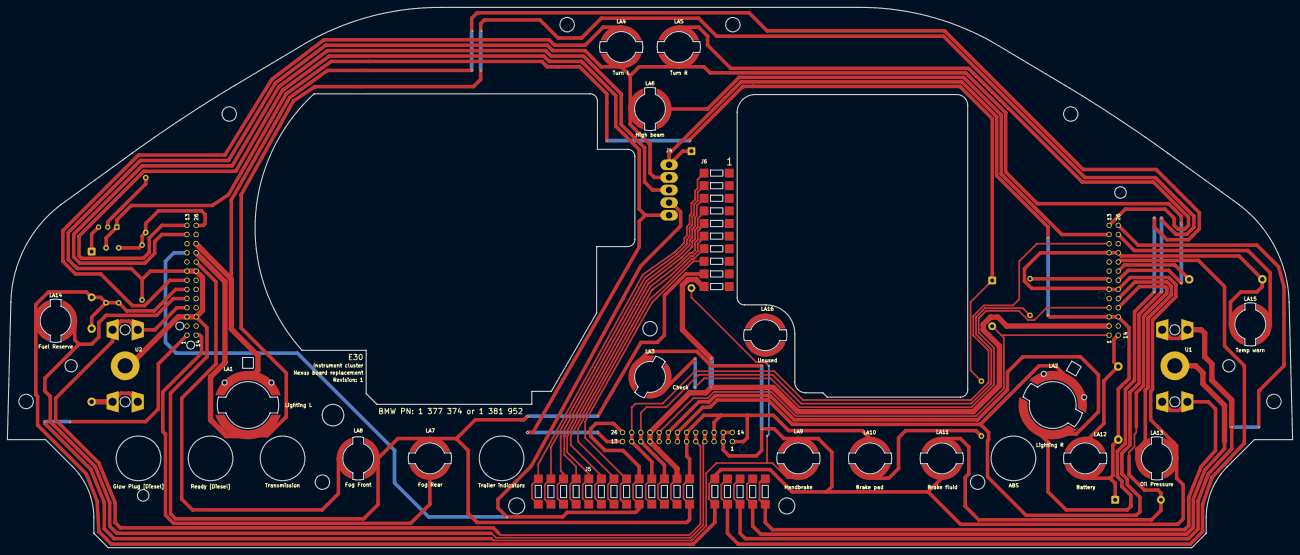
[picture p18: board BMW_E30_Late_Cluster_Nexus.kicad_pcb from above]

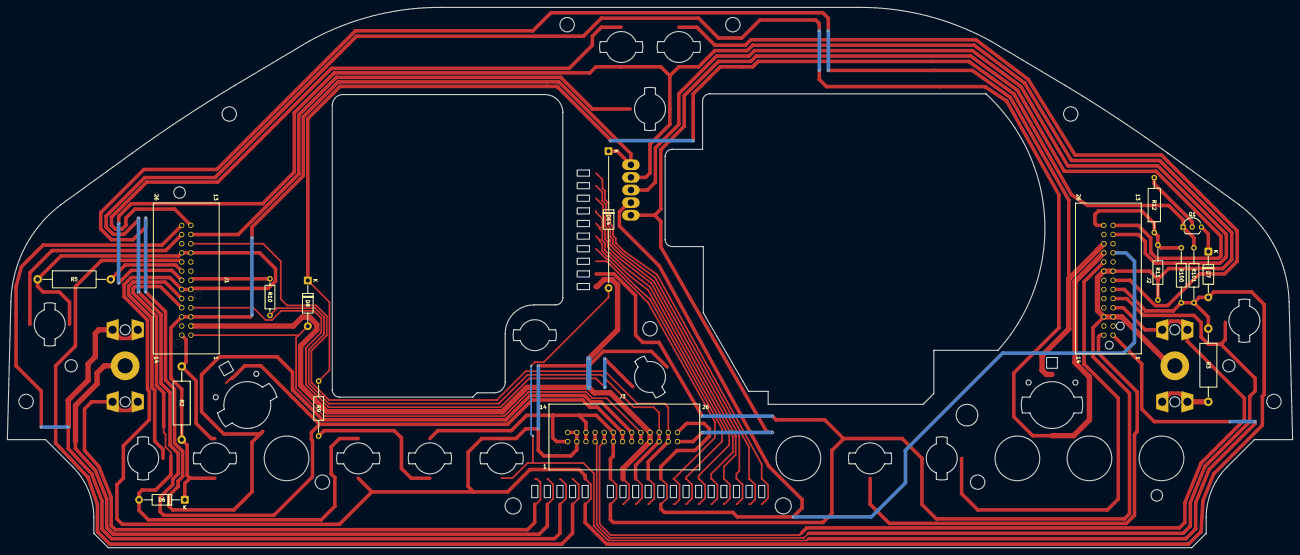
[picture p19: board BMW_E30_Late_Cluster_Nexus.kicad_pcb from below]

Board: 2 copper layers, 356.8 x 150.0 mm, 38 parts (17 on the bottom side), 45 nets.

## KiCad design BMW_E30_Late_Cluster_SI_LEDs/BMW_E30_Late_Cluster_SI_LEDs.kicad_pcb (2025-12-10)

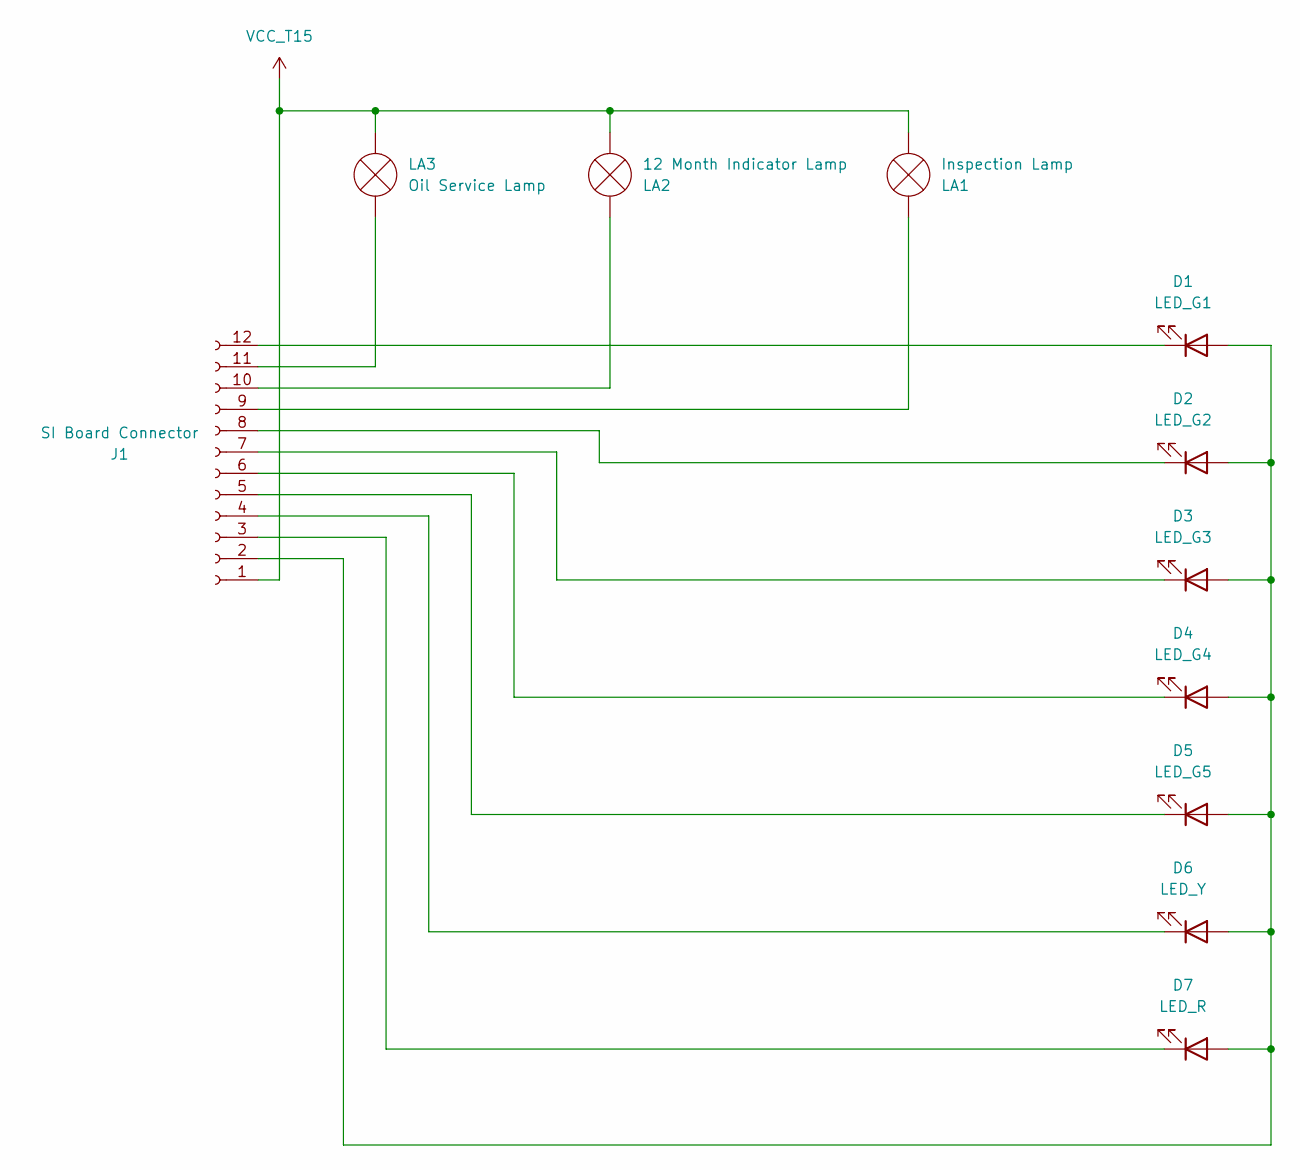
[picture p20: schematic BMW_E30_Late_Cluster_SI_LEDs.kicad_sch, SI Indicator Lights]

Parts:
D1: LED_G1; LED_D3.0mm
D2: LED_G2; LED_D3.0mm
D3: LED_G3; LED_D3.0mm
D4: LED_G4; LED_D3.0mm
D5: LED_G5; LED_D3.0mm
D6: LED_Y; LED_D3.0mm
D7: LED_R; LED_D3.0mm
J1: SI Board Connector; PinSocket_1x12_P2.54mm_Horizontal
LA1: Inspection Lamp; Lamp_D4.0mm_Horizontal_O3.81mm_Z2.0mm
LA2: 12 Month Indicator Lamp; Lamp_D4.0mm_Horizontal_O3.81mm_Z2.0mm
LA3: Oil Service Lamp; Lamp_D4.0mm_Horizontal_O3.81mm_Z2.0mm

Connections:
unnamed: D1.2 (A), D2.2 (A), D3.2 (A), D4.2 (A), D5.2 (A), D6.2 (A), D7.2 (A), J1.2
unnamed: D1.1 (K), J1.12
unnamed: D2.1 (K), J1.8
unnamed: D3.1 (K), J1.7
unnamed: D4.1 (K), J1.6
unnamed: D5.1 (K), J1.5
unnamed: D6.1 (K), J1.4
unnamed: D7.1 (K), J1.3
unnamed: J1.9, LA1.1 (-)
unnamed: J1.10, LA2.1 (-)
unnamed: J1.11, LA3.2 (+)
VCC_T15: J1.1, LA1.2 (+), LA2.2 (+), LA3.1 (-)

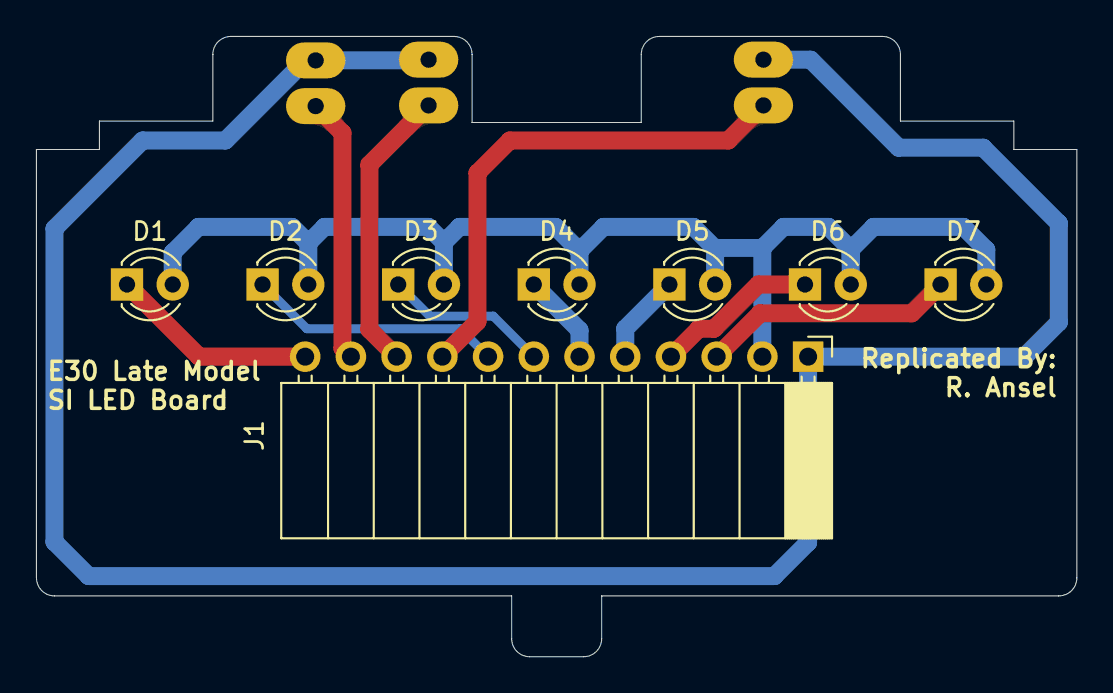
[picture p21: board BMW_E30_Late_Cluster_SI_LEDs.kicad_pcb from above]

Board: 2 copper layers, 57.8 x 34.5 mm, 11 parts (0 on the bottom side), 12 nets.

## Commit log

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2025-11-02 Updates to Nexus Schematic
    C1 - C4 have all pins named. Break wear circuit completed.
    [BMW_E30_Late_Cluster_Nexus.kicad_sch, Pinout.ods]
2025-11-02 Nexus Schematic Complete Rough
    All connectors are pinned and labeled. Should likely do a double check to verify everything is good and then layout can begin.
    [BMW_E30_Late_Cluster_Nexus.kicad_sch, Brake_Wear.kicad_sch]
2025-11-03 All Footprints Added to Nexus
    All footprints have been added to the nexus board project. Next step is to import them to the layout.
    [BMW_E30_Late_Cluster_Nexus.kicad_pcb, BMW_E30_Late_Cluster_Nexus.kicad_sch, Brake_Wear.kicad_sch]
2025-11-03 Fixed Library to be project specific
    connector library was originally global which was messing with other projects, changed to local for now (might consolidate this later depending on how I want it to work.
2025-11-03 Fix Outdated Connector IV Hole Sizes
2025-11-08 Nexus Layout Updates
    Layout is about 50% complete. Need to verify exact component locations with early model board.
    [BMW_E30_Late_Cluster_Nexus.kicad_pcb, BMW_E30_Late_Cluster_Nexus.kicad_sch, Brake_Wear.kicad_sch]
2025-11-08 Nexus Trace Layout Completed
    Trace layout is complete. Still need to verify some component locations
    [BMW_E30_Late_Cluster_Nexus.kicad_pcb]
2025-11-08 Rotate Right Illum Bulb
    Changed orientation of the right side illumination bulb
    [BMW_E30_Late_Cluster_Nexus.kicad_pcb]
2025-11-09 Standardized Board Location In Editor
    Made the board location the same in both projects so component locations can be corrected from sample runs of the early boards.
    [BMW_E30_Late_Cluster_Nexus.kicad_pcb]
2025-11-10 Layout Updates to Match Early
    Changed a few light bulb component locations to match the correct locations on the early model boards.
    [BMW_E30_Late_Cluster_Nexus.kicad_pcb, BMW_E30_Late_Cluster_Nexus.kicad_sch]
2025-11-11 Added Project Files + Updates
    Added project files for SI LED daughter board and speedometer board. Started on reverse engineering schematic for late model SI board.
    Also updated some formatting on the nexus board schematic.
    [BMW_E30_Late_Cluster_Nexus.kicad_sch, BMW_E30_Late_Cluster_SI.kicad_sch, BMW_E30_Late_Cluster_SI_LEDs.kicad_pcb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]
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2025-11-13 Board Updates
    Added a few components + footprints.
    Also added custom Connector V footprint, ported from Fabian Gmeiner's early model SI board project.
    [BMW_E30_Late_Cluster_SI.kicad_pcb, BMW_E30_Late_Cluster_SI.kicad_sch]
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2025-11-16 Schematic Updates to SI board
    Added more resistors and diodes. Only resistors and diodes remain to be entered.
    [BMW_E30_Late_Cluster_SI.kicad_sch]
2025-11-17 updates to SI schematic
    Added several more resistors and diodes to the SI schematic.
    [BMW_E30_Late_Cluster_SI.kicad_sch]
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2025-11-18 Update SI Schematic
    Added all of the components except for the 4 IC's. Those will require custom footprints as the chips are NLA with no datasheets.
    [BMW_E30_Late_Cluster_SI.kicad_sch]
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2025-11-22 Schematic Progress
    All components other than IC's are accounted for in the schematic. There are still IC1 - IC4 that need custom symbols and will have a few more traces in between pins than are currently shown in the s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
    [BMW_E30_Late_Cluster_SI.kicad_sch, Indicator_Lights.kicad_sch]
2025-11-24 IC's Added to Schematic
    IC's added, started going through IC2 (U2), pinouts not complete for these yet as many pins go between chips with no other components involved.
    [BMW_E30_Late_Cluster_SI.kicad_sch, Indicator_Lights.kicad_sch]
2025-11-24 Schematic Functionally Complete
    Only changes that should need to be made are formatting and style changes to improve readability.
    [BMW_E30_Late_Cluster_SI.kicad_sch, Indicator_Lights.kicad_sch, Temperature_Sensor.kicad_sch]
2025-11-25 Improved Schematic Readability for SI Board
    Added final trace flags for readability of the main page. Also exported a BOM for the SI board
    [BMW_E30_Late_Cluster_SI.kicad_sch, BMW_E30_Late_Cluster_SI_BOM.xlsm, Temperature_Sensor.kicad_sch]
2025-11-27 Completed Schematic + Layout for SI LED
    Additional labels were added to the SI board schematic to denote which pin controls which light on the LED board.
    [BMW_E30_Late_Cluster_SI_LEDs.kicad_pcb, BMW_E30_Late_Cluster_SI_LEDs.kicad_sch, Indicator_Lights.kicad_sch]
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2025-12-02 Component Locations Generally Set
    Component locations set up and ready for layout to begin.
    [BMW_E30_Late_Cluster_SI.kicad_pcb, BMW_E30_Late_Cluster_SI.kicad_sch]
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2025-12-05 SI Board Layout Updates
    Continued updating traces from the coding plug side of the board.
    [BMW_E30_Late_Cluster_SI.kicad_pcb]
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2025-12-07 Readability Improvements
    Organized the schematic for better readability, also made a few minor adjustments to the layout for simplicity.
    [BMW_E30_Late_Cluster_SI.kicad_pcb, BMW_E30_Late_Cluster_SI.kicad_sch, Indicator_Lights.kicad_sch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]
2025-12-10 Board Styling on SI and SI LED
    Added fillets to the SI and SI_LED boards and generated the first gbr files for pricing estimation on JLC.
    [BMW_E30_Late_Cluster_SI.kicad_pcb, BMW_E30_Late_Cluster_SI_LEDs.kicad_pcb]
2025-12-18 Updates for GBR files
    Slight stylistic improvements for GBR files as well as added some links to parts on digikey.
    [BMW_E30_Late_Cluster_SI.kicad_sch, BMW_E30_Late_Cluster_SI_LEDs.kicad_sch, Indicator_Lights.kicad_sch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]
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2025-12-31 Change location of Coding Plug Connector
    Updated coding plug connector to be lower so that it interfaces with the coding plug better.
    [BMW_E30_Late_Cluster_SI.kicad_pcb]
2026-01-01 Layout Update + Schematic Style
    Widened a problematic cutout in the layout for V2 of the board. Also made small stylistic improvements to Schematic.
    [BMW_E30_Late_Cluster_SI.kicad_pcb, BMW_E30_Late_Cluster_SI.kicad_sch]
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2026-01-11 Fixed Error in edge cut layer
    [BMW_E30_Late_Cluster_SI.kicad_pcb, BMW_E30_Late_Cluster_SI.kicad_sch]
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2026-02-22 Layout fixes
    Some traces were not connected.
    [BMW_E30_Late_Cluster_SI.kicad_pcb]
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
